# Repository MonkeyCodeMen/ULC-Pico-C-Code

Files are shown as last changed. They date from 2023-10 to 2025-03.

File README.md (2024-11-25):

# **ULC Pico   (Universal Light Controller on Raspberry Pico)**

All started with the purchasing of Raspberry Pico RP2040 in 2023. 

a fascinating dual core processor for less than 5€ (gosh do you know what we have paied for Z80 or 68K when I started with µController) .. congratulation to the raspberry foundation good job

The Arduino IDE beacomes to small for this number files so I changed to Visual Studio Code with PlatformIO
.. fascinating all for free .. and the integration of RP2040 from maxgerhardt outstanding .. Thanks a lot

I tried several other things like:

+ Rapberry Pico Debuger 
+ Unity test
+ embedded dual core arcitecture With debugging 
+ LED stripes, RGB LED Stripes, WS2812B LED stripes, WS2812B LED Matrix
+ SD card
+ Advent calender
+ Real Time Clock
+ SPI Display
+ I2C Slave (Arduino Nano)
+ I2C keyboard
+ GIF animations of WS2812B Matrix
+ advent calendar with gifs
Layout
Layout

.. I think I show you a picture of the current state:
system architecture

I just want to explore how it works and it lead to this  .. but it will not be the end, it just reached a state where I decided to make it public to give something back to the community, in the hope it may be usefull for somebody. 
And don’t forget: always stay curious and persistent. The best way to learn is through mistakes. But only those who try something new and unfamiliar can make mistakes to learn from. Every day without learning something is a lost day.

So, search behind every tree and under very stone for the three-headed monkey, and if you need a boat, just ask for Stan.

The project keeps growing and growing .. I needed a PCB .. I found KiCad :
@KiCad Team .. a professional layout tool for free .. great work ... 

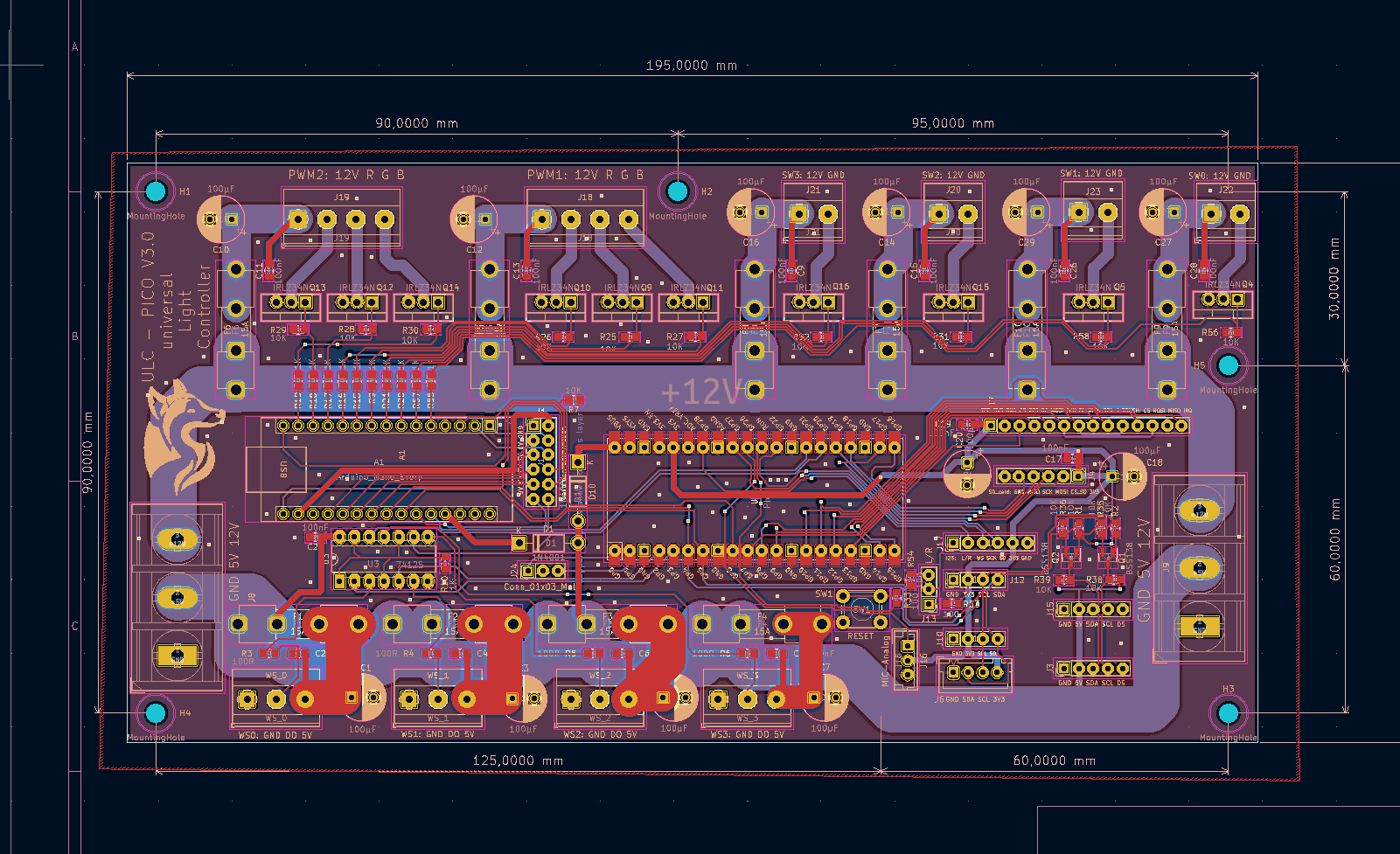
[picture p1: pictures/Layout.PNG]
Layout


there were now a lot of components so I needed a hosuing 
.. you will not belief there is a free M-CAD tool : freecad 

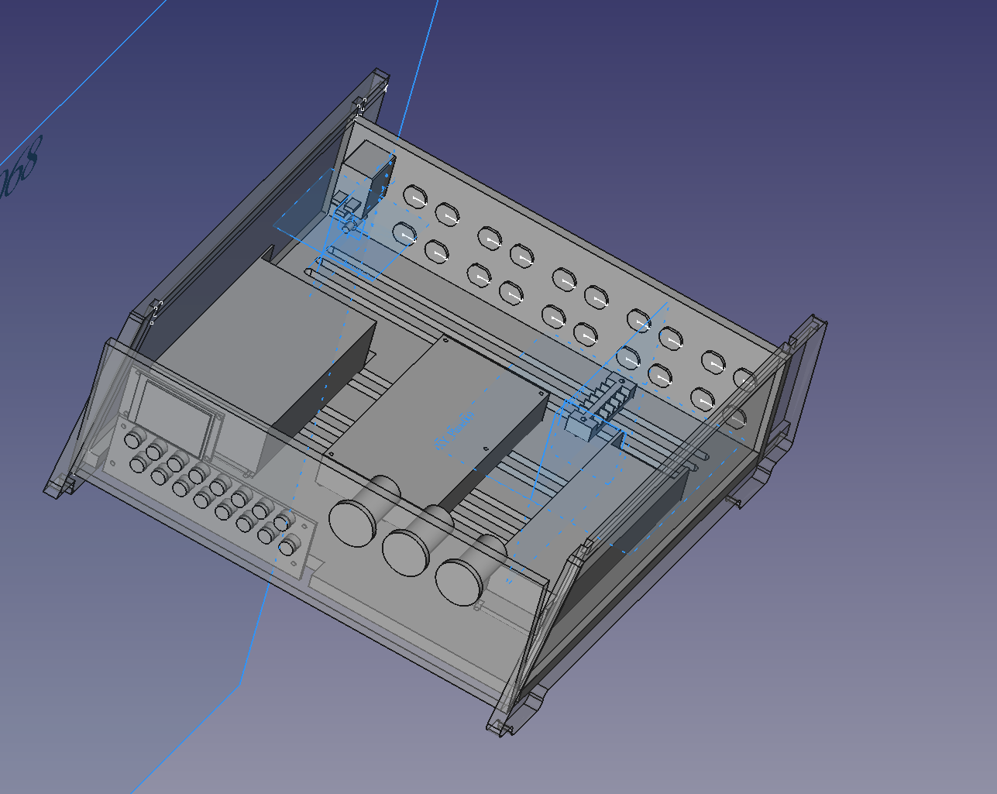
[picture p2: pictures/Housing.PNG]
housing


I build all in wood an milled it on my MP CNC (a nice free project for CNC machine please look for it)
And this is the final result:

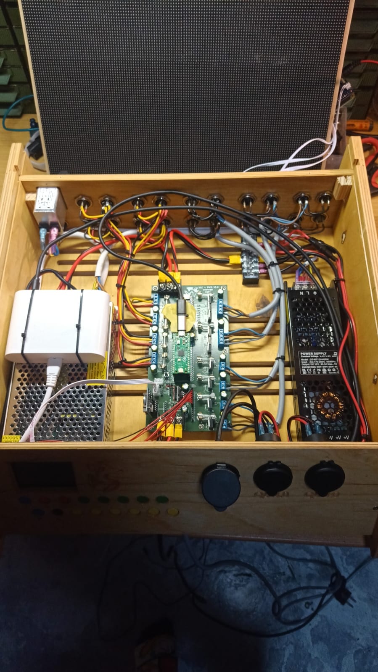
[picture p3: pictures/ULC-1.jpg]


and what can I do ?
----------------
mainly it control several types of LED (a lot of them)

one example a advent calendar for nurds:
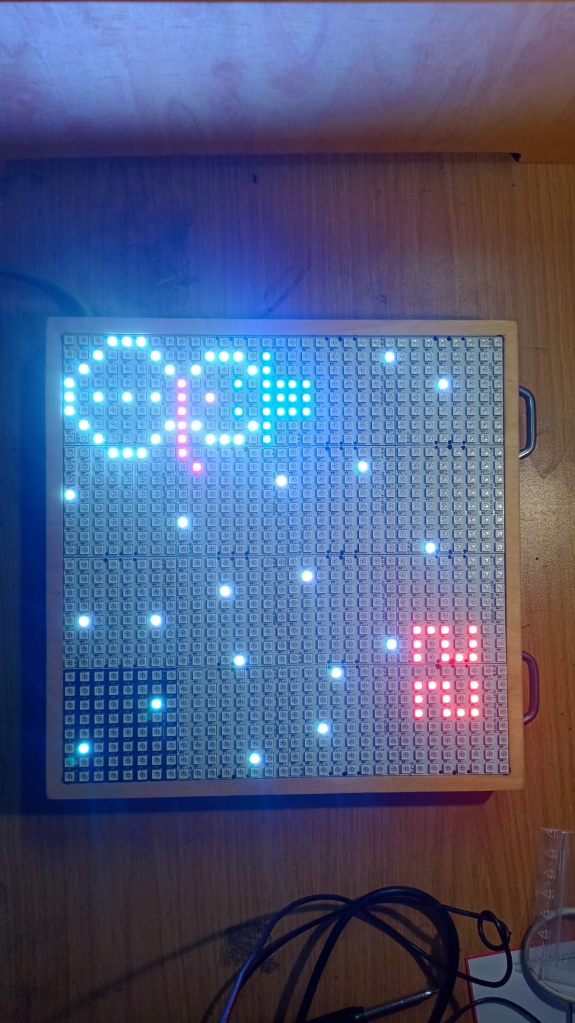
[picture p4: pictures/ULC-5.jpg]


some more details:
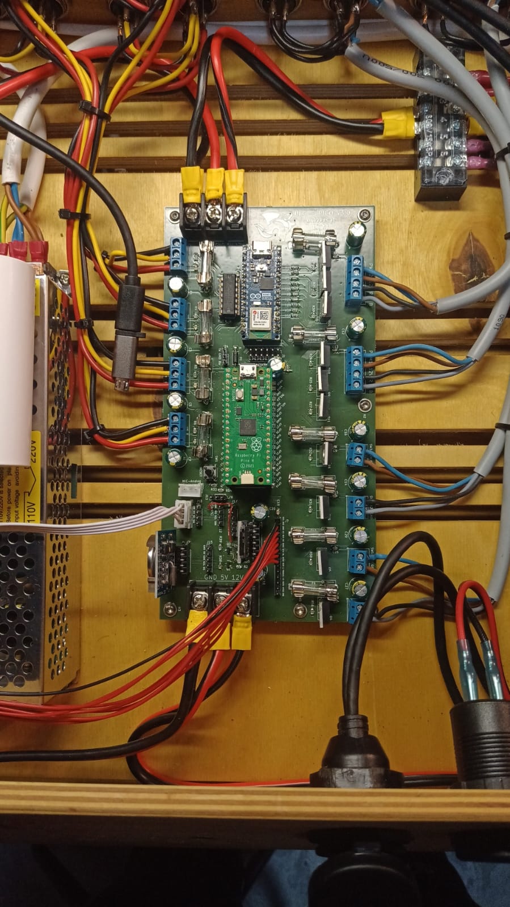
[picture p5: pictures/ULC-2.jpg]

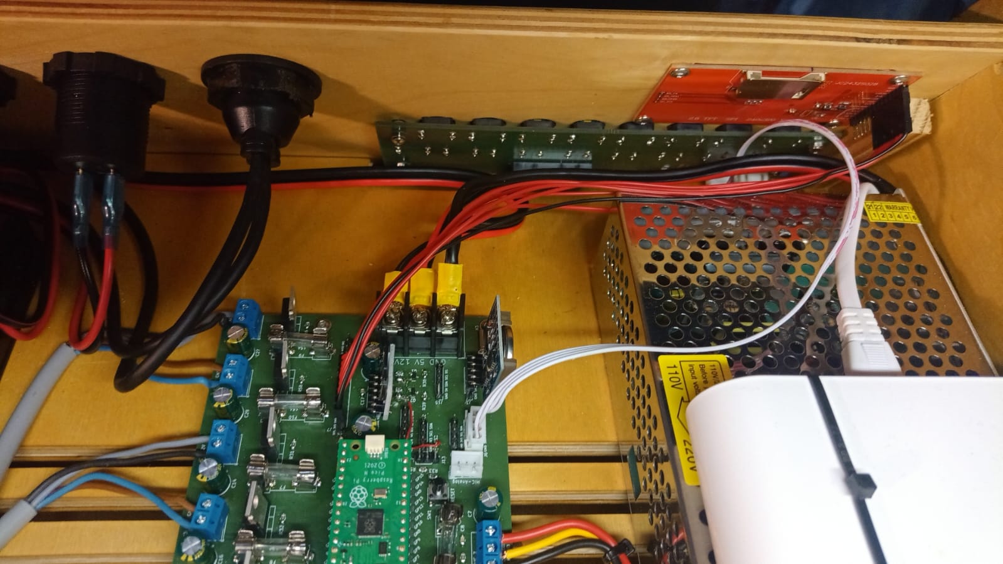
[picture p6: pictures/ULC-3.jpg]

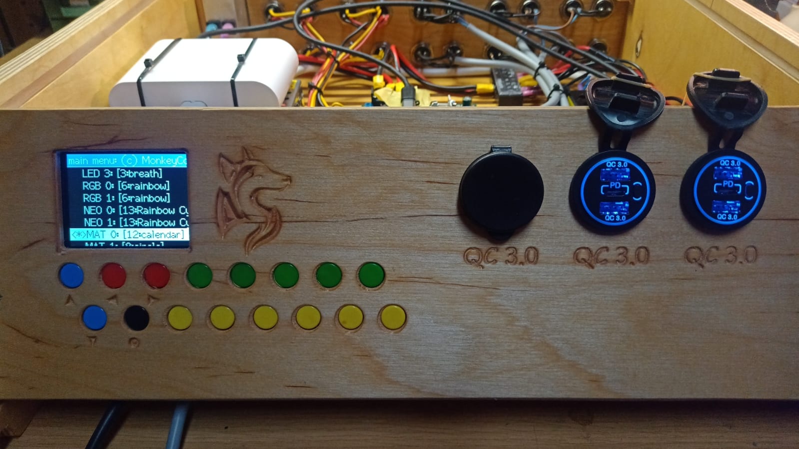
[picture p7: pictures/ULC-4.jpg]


---

## **Table of Contents**
- [System architecture](#system-architecture)
- [Software architecture](#software-architecture)
- [Required Libraries](#required-libraries)
- [Installation](#installation)
- [Usage](#usage)
- [Configuration](#configuration)
- [Unit Test](#unit-test)
- [Contributing](#contributing)
- [License](#license)

---
## **System architecture**
system architecture

---
## **Software architecture**
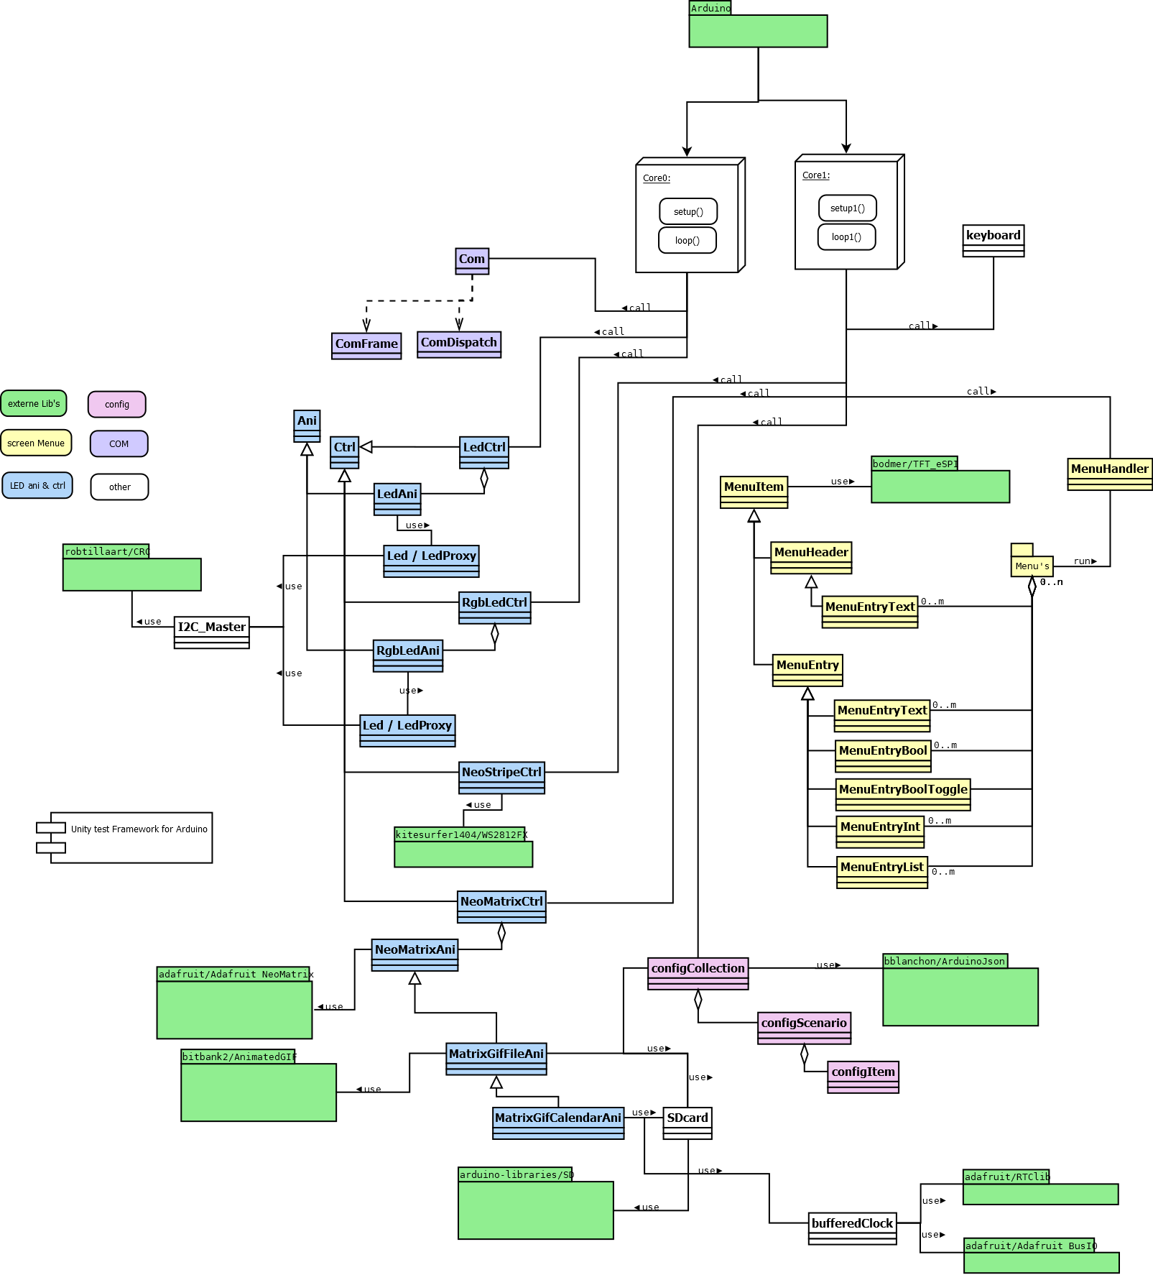
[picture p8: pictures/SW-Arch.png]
software architecture


I staied with the Arduino loop concept and designed the most classes in this manner. This is not suitable for hard real time rqeuirement, but it is easy and with the performance of the two cores of the RP2040 it is amazing what is possible.

But from my experience I use during one loop run a fixed time (now). I freeze this time at the begin of the loop and pass it than to every module that is been called in this loop. 

In addition to that I have a favor for the rough concept of state-machine with init run etc... 

For more details please refer the comment of the individual classes.

ToDo description to : 
+ multi core problems - MUTEX handling 

---

## **Required Libraries**

Below is a list of the libraries or frameworks required for the project to run. Make sure to install them before proceeding.

Many thanks to all the amazing developers of these libraries. Based on this foundation, it is possible to create larger projects like this one with a moderate amount of time. This enables significantly more functionality than would have been achievable by a single person alone.

All Lib's will be installed by PlatformIO based on ini file .. perfect .. @PlatforIO team: outstanding job, i know several professional tools from automobile industry that can not do this !!!!

### from Arduino:
+ Arduino base
+ wire
+ spi
+ SD

### RP2040 Toolchain 
https://github.com/maxgerhardt/platform-raspberrypi.git

### form adafruit: Adafruit BusIO @ ^1.16.2
+ RTClib @ ^2.1.4
+ Adafruit NeoMatrix @ ^1.3.3
  
### form bodmer:
+ TFT_eSPI @ ^2.5.43

### from kitesurfer1404:
+ WS2812FX @ ^1.4.4
  A beautiful and extensive library with many animations for intelligent RGB LEDs. Truly professional and exceptionally impressive work. Thank you so much for making something like this available!
  
### bitbank2:
+ AnimatedGIF @ ^2.1.1
  a real handy lib to handle GIF's thanks .. It would have cost me several monthes to do somthing that will be for sure not at this level ... Thanks
  
### robtillaart:
+ CRC @ ^1.0.3

### bblanchon:
+ ArduinoJson @ ^7.2.1

@all LIB authors .. great job, please keep up this good work 

---

## **Installation**

### **Prerequisites**
- SW: 
+ install Visual Studio Code
+ in Visual Studio install PlatformIO extension
- HW:
+ Install Kicad 
- Mechanic:
+ Install freeCad

### **Steps**
1. clone this project from GitHub (you can use Visual Studio Code interface or download it per WEB interface)
   ```bash
   git clone https://github.com/MonkeyCodeMen/ULC-Pico-C-Code.git

---

## **Configuration**

ToDo

---

## **Unit Test**

ToDo

---

## **License**

The MIT License (MIT)

Copyright (c) 2024 MonkeyCodeMen@GitHub

Permission is hereby granted, free of charge, to any person obtaining a copy
of this software and associated documentation files (the "Software"), to deal
in the Software without restriction, including without limitation the rights
to use, copy, modify, merge, publish, distribute, sublicense, and/or sell
copies of the Software, and to permit persons to whom the Software is
furnished to do so, subject to the following conditions:

The above copyright notice and this permission notice shall be included in all
copies or substantial portions of the Software.

THE SOFTWARE IS PROVIDED "AS IS", WITHOUT WARRANTY OF ANY KIND, EXPRESS OR
IMPLIED, INCLUDING BUT NOT LIMITED TO THE WARRANTIES OF MERCHANTABILITY,
FITNESS FOR A PARTICULAR PURPOSE AND NONINFRINGEMENT. IN NO EVENT SHALL THE
AUTHORS OR COPYRIGHT HOLDERS BE LIABLE FOR ANY CLAIM, DAMAGES OR OTHER
LIABILITY, WHETHER IN AN ACTION OF CONTRACT, TORT OR OTHERWISE, ARISING FROM,
OUT OF OR IN CONNECTION WITH THE SOFTWARE OR THE USE OR OTHER DEALINGS IN THE
SOFTWARE.

have fun !!

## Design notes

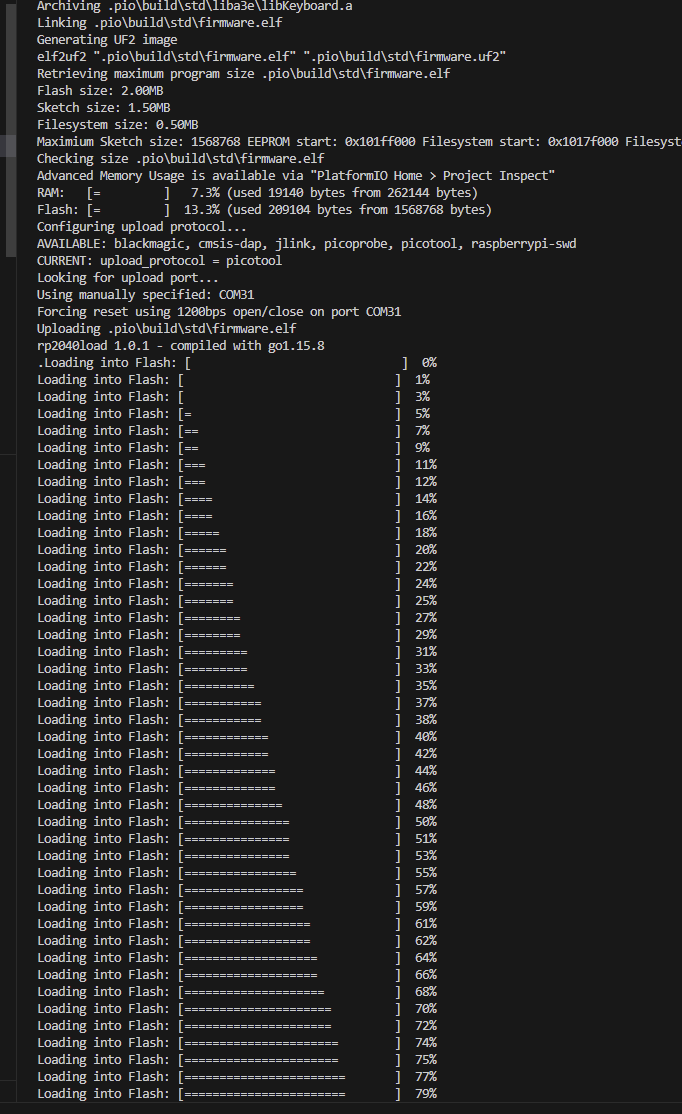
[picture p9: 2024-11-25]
pictures/USB-Flash-2.PNG

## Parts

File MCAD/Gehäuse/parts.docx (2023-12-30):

Front part dicke 9mm Fräser 6mm

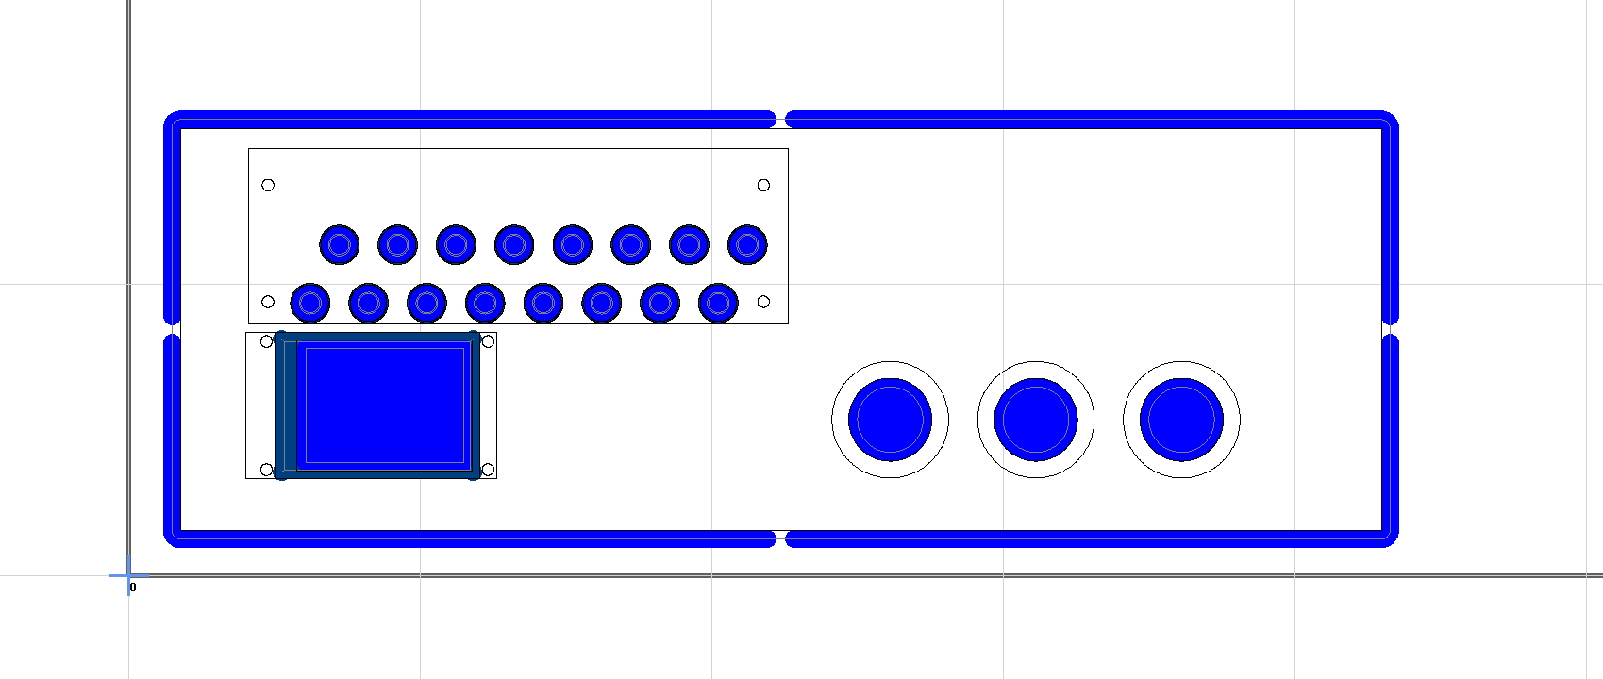
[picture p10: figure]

Front – Frässer 6mm (von hinten)

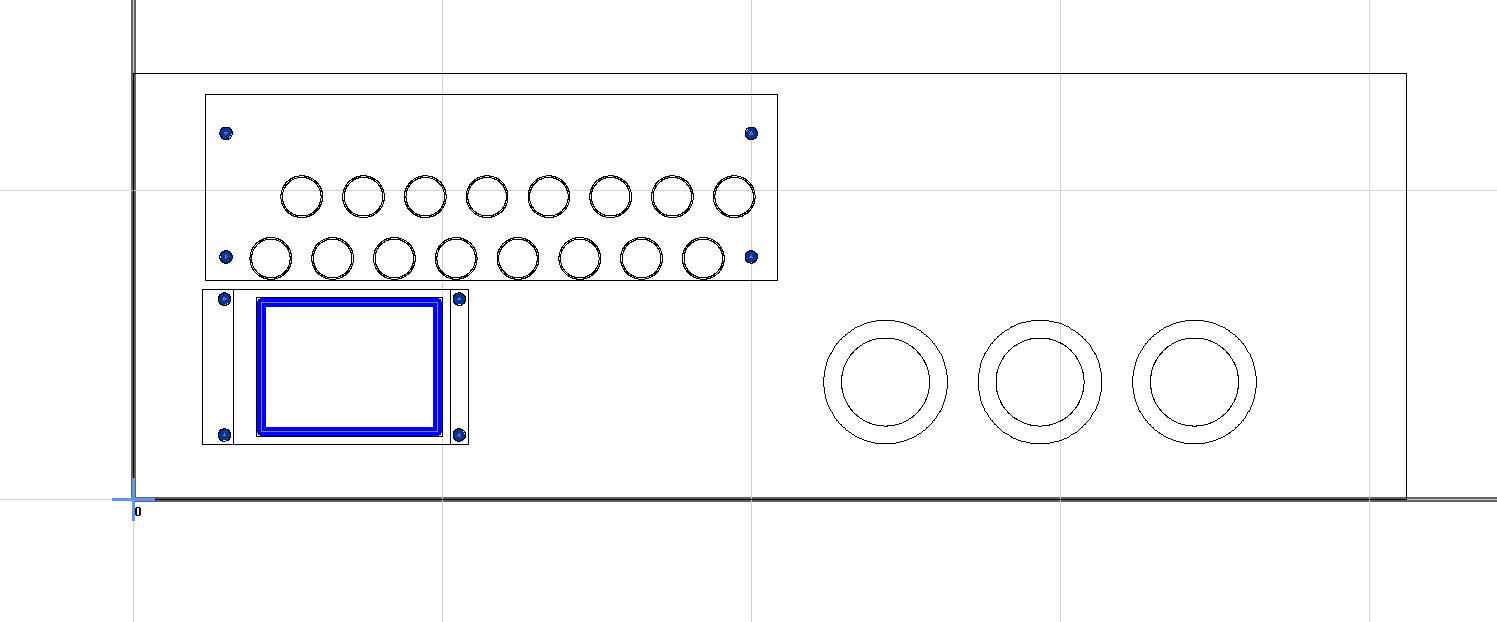
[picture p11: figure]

Front – Fräser Spitze 45 Grad von vorne

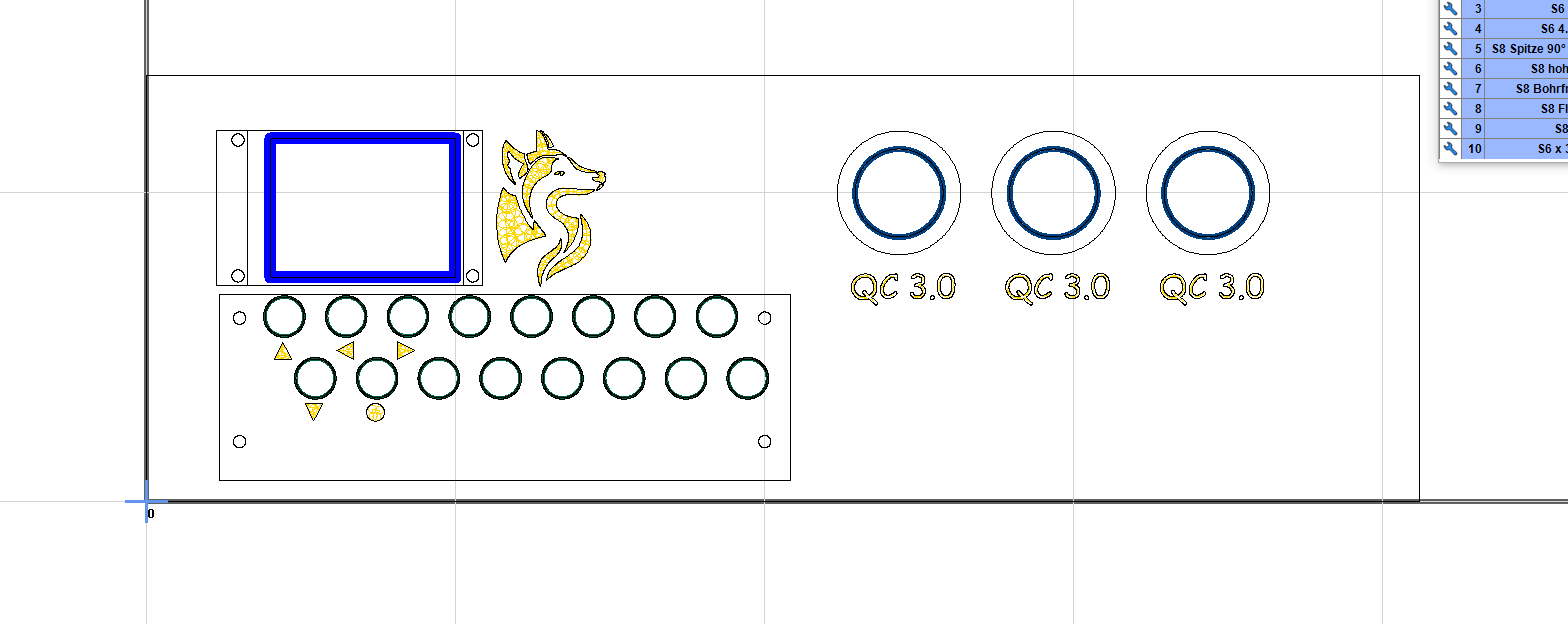
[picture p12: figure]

Back – dicke 9mm Fräser 6mm

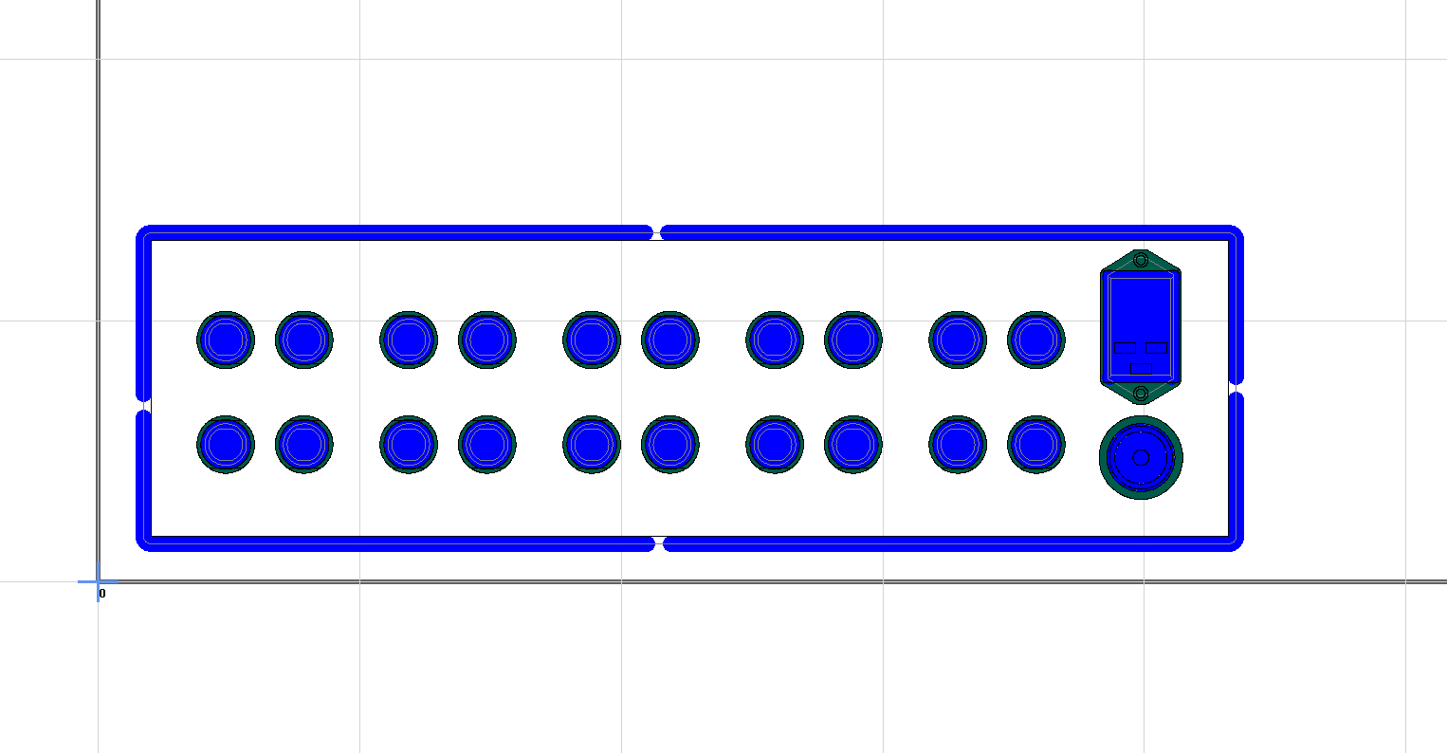
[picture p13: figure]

Back – von hinten außen Fräser 45 Grad

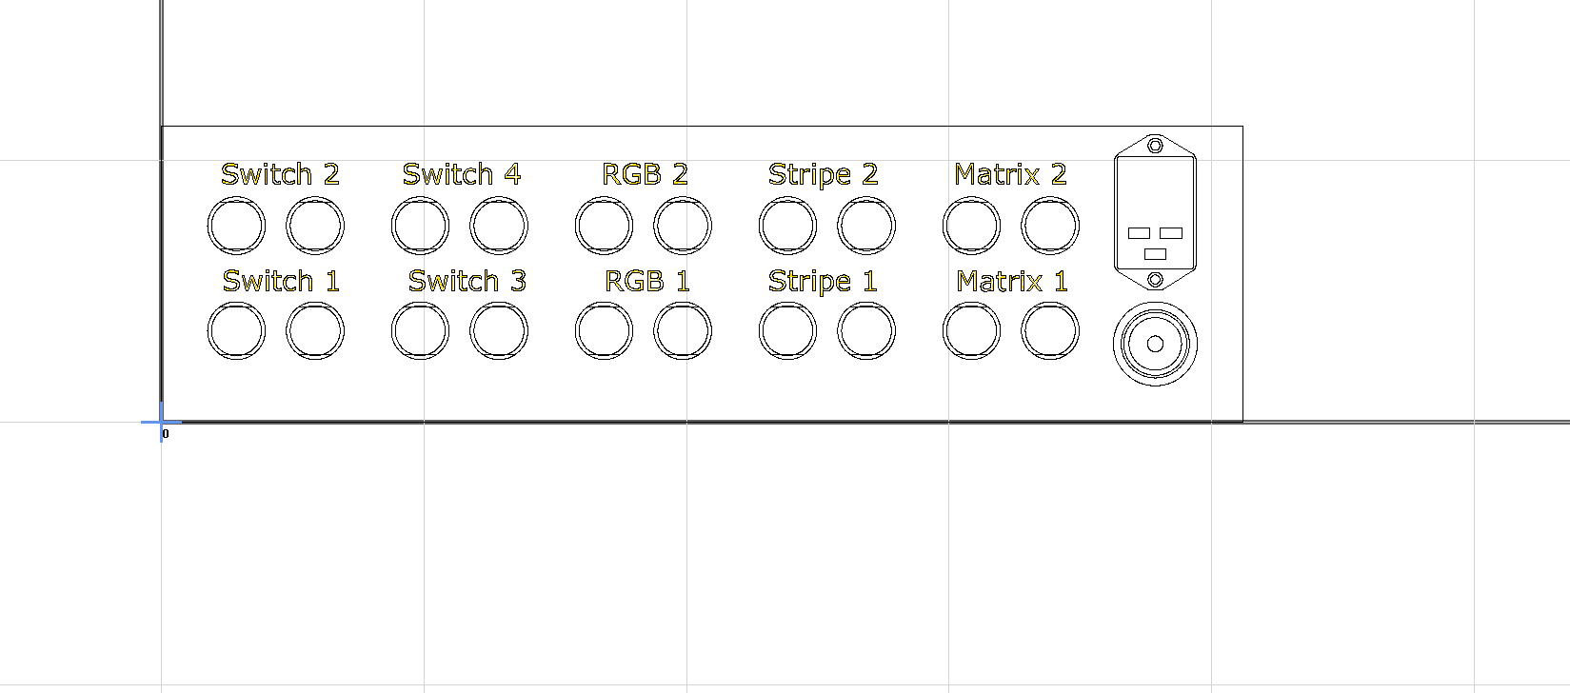
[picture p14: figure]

Bottom part dicke 12 mm –Fräser 6mm

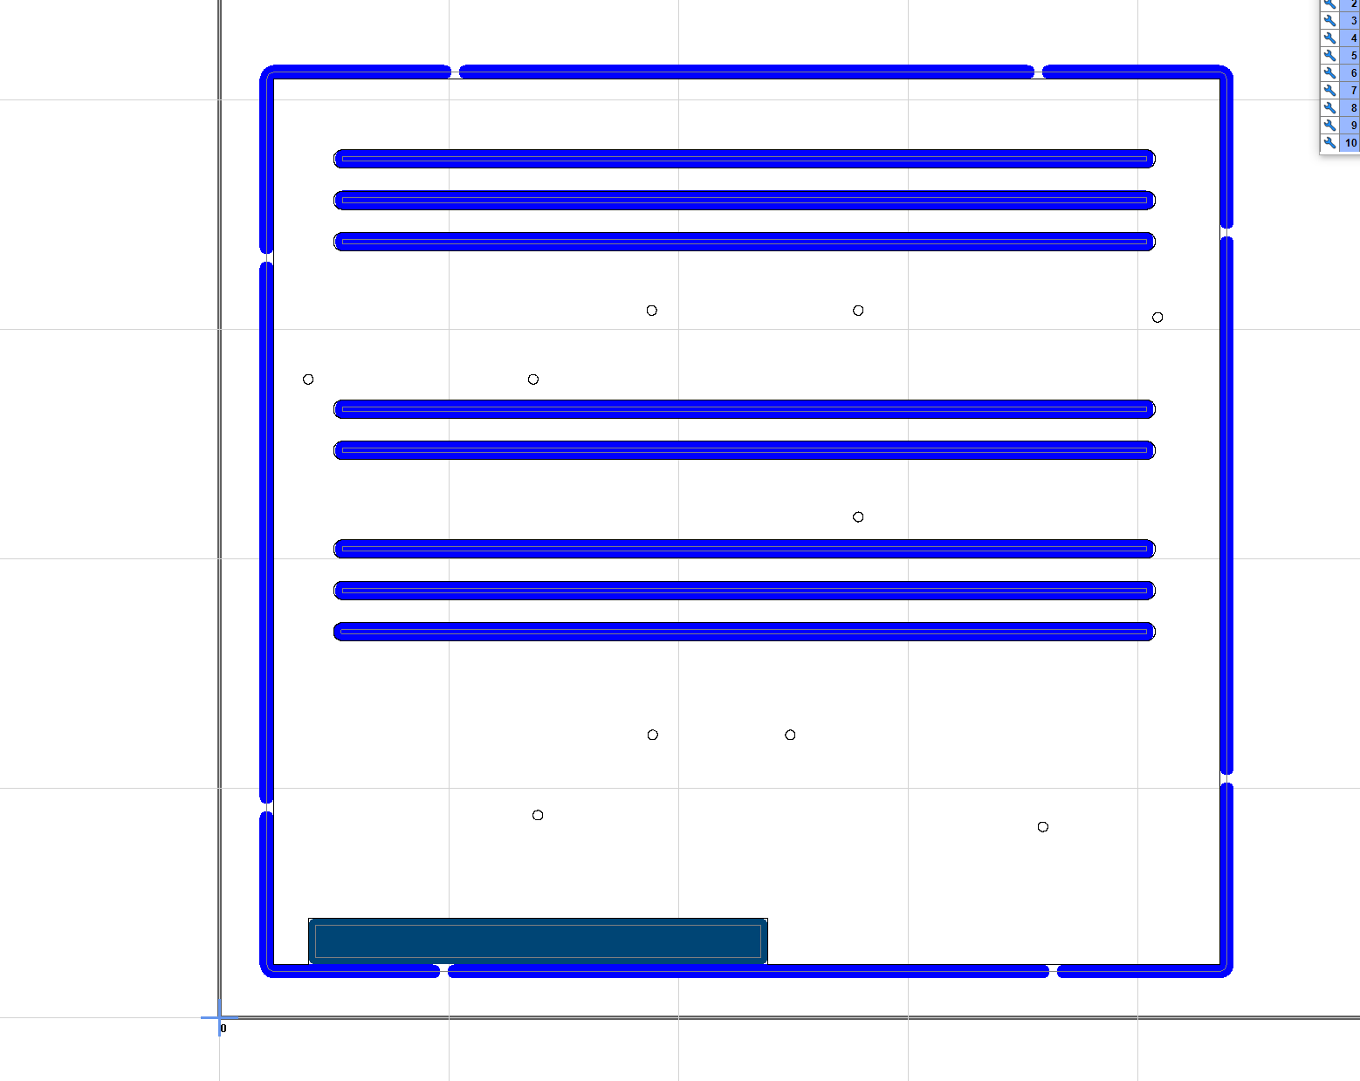
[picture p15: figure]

Bottom – drills –Fräser 3mm:

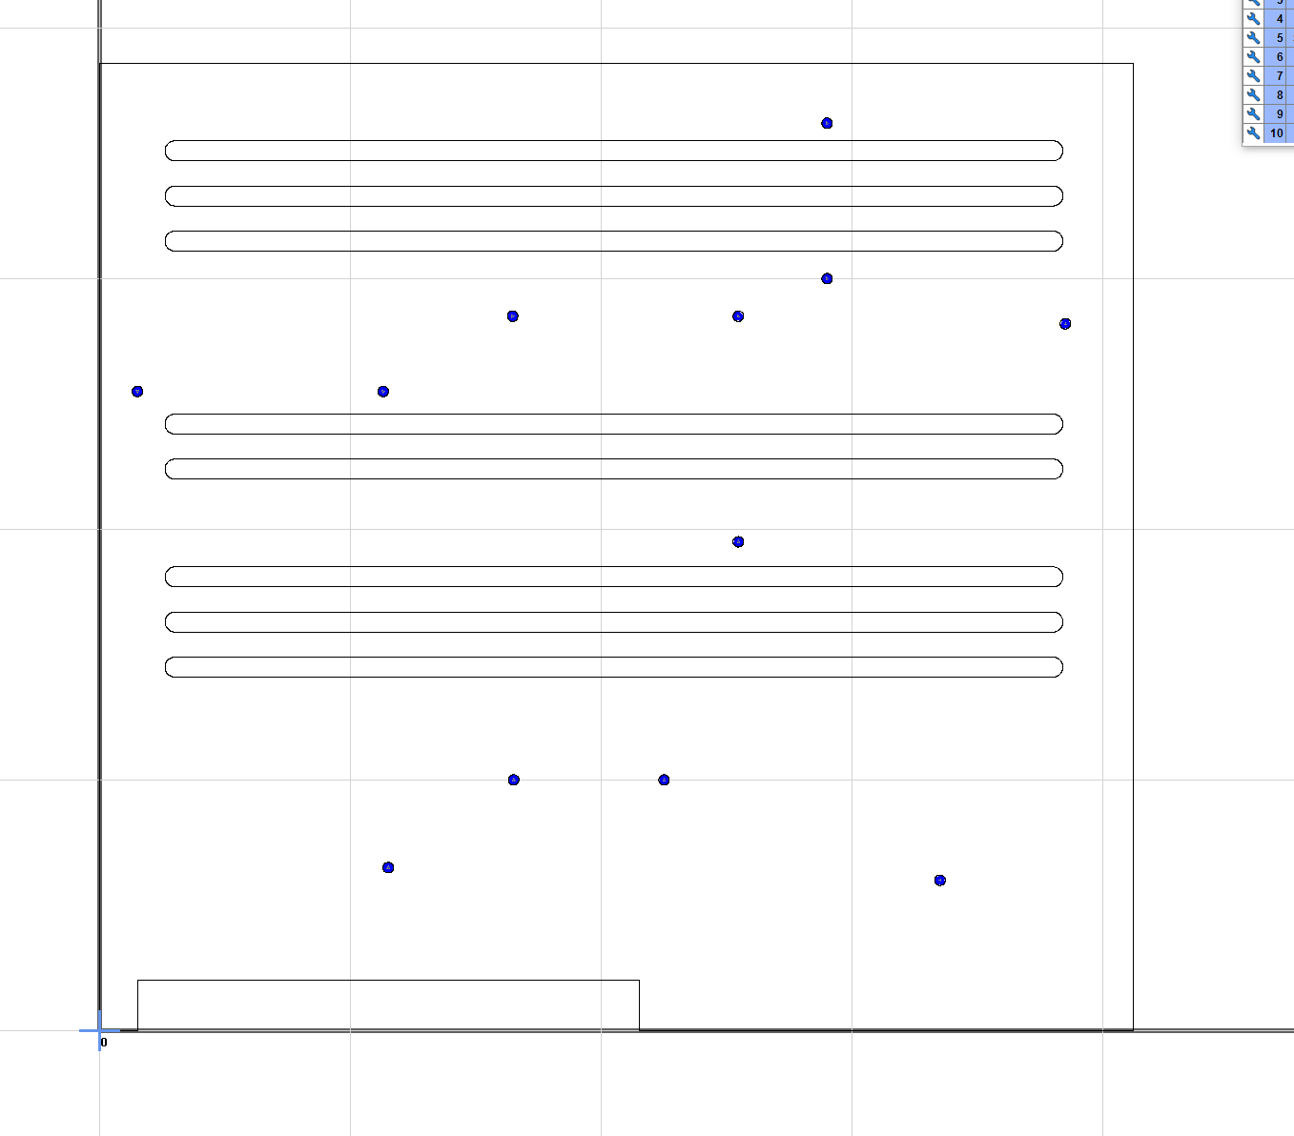
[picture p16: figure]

Top dicke 6mm – Fräser 6mm:

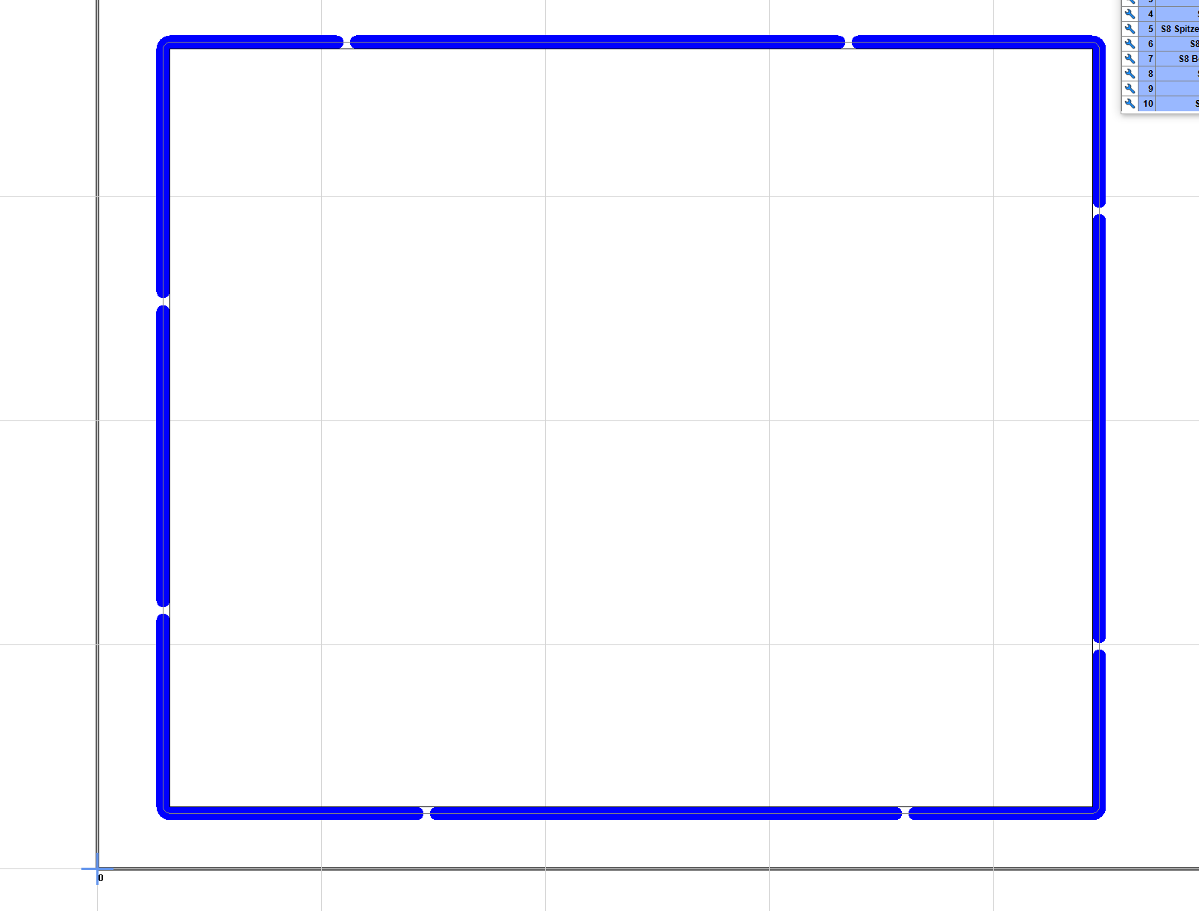
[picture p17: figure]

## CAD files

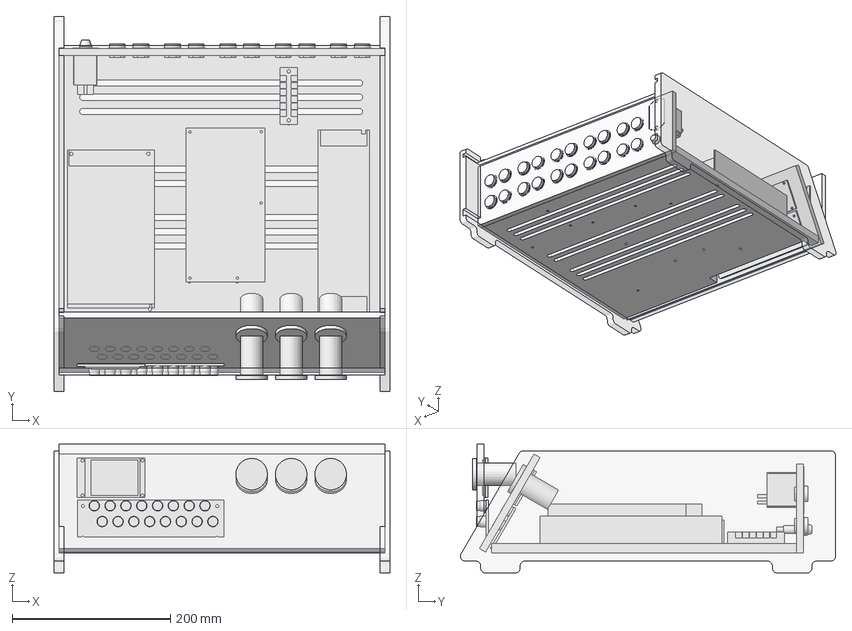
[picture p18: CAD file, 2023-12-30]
MCAD/Gehäuse/Gehäuse_1.FCStd
425.0 x 474.6 x 163.0 mm
right side
left side
bottom
front
Top
rear
Supply 12V-30A
Supply-5V-40A
PCB-ULC_PICO-VER3
Klemmblock 6x2
Netzeingang
FuseHolder
Connector
Connector001
Connector002
Connector003
Connector004
Connector005
Connector006
Connector007
Connector008
Connector009
Connector010
Connector011
Connector012
Connector013
Connector014
Connector015
Connector016
Connector017
Connector018
Connector019
Display
buttons
charger
charger 001
charger 002
Front Fragment
rear Fragments

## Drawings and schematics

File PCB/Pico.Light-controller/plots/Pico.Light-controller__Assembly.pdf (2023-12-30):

A

A

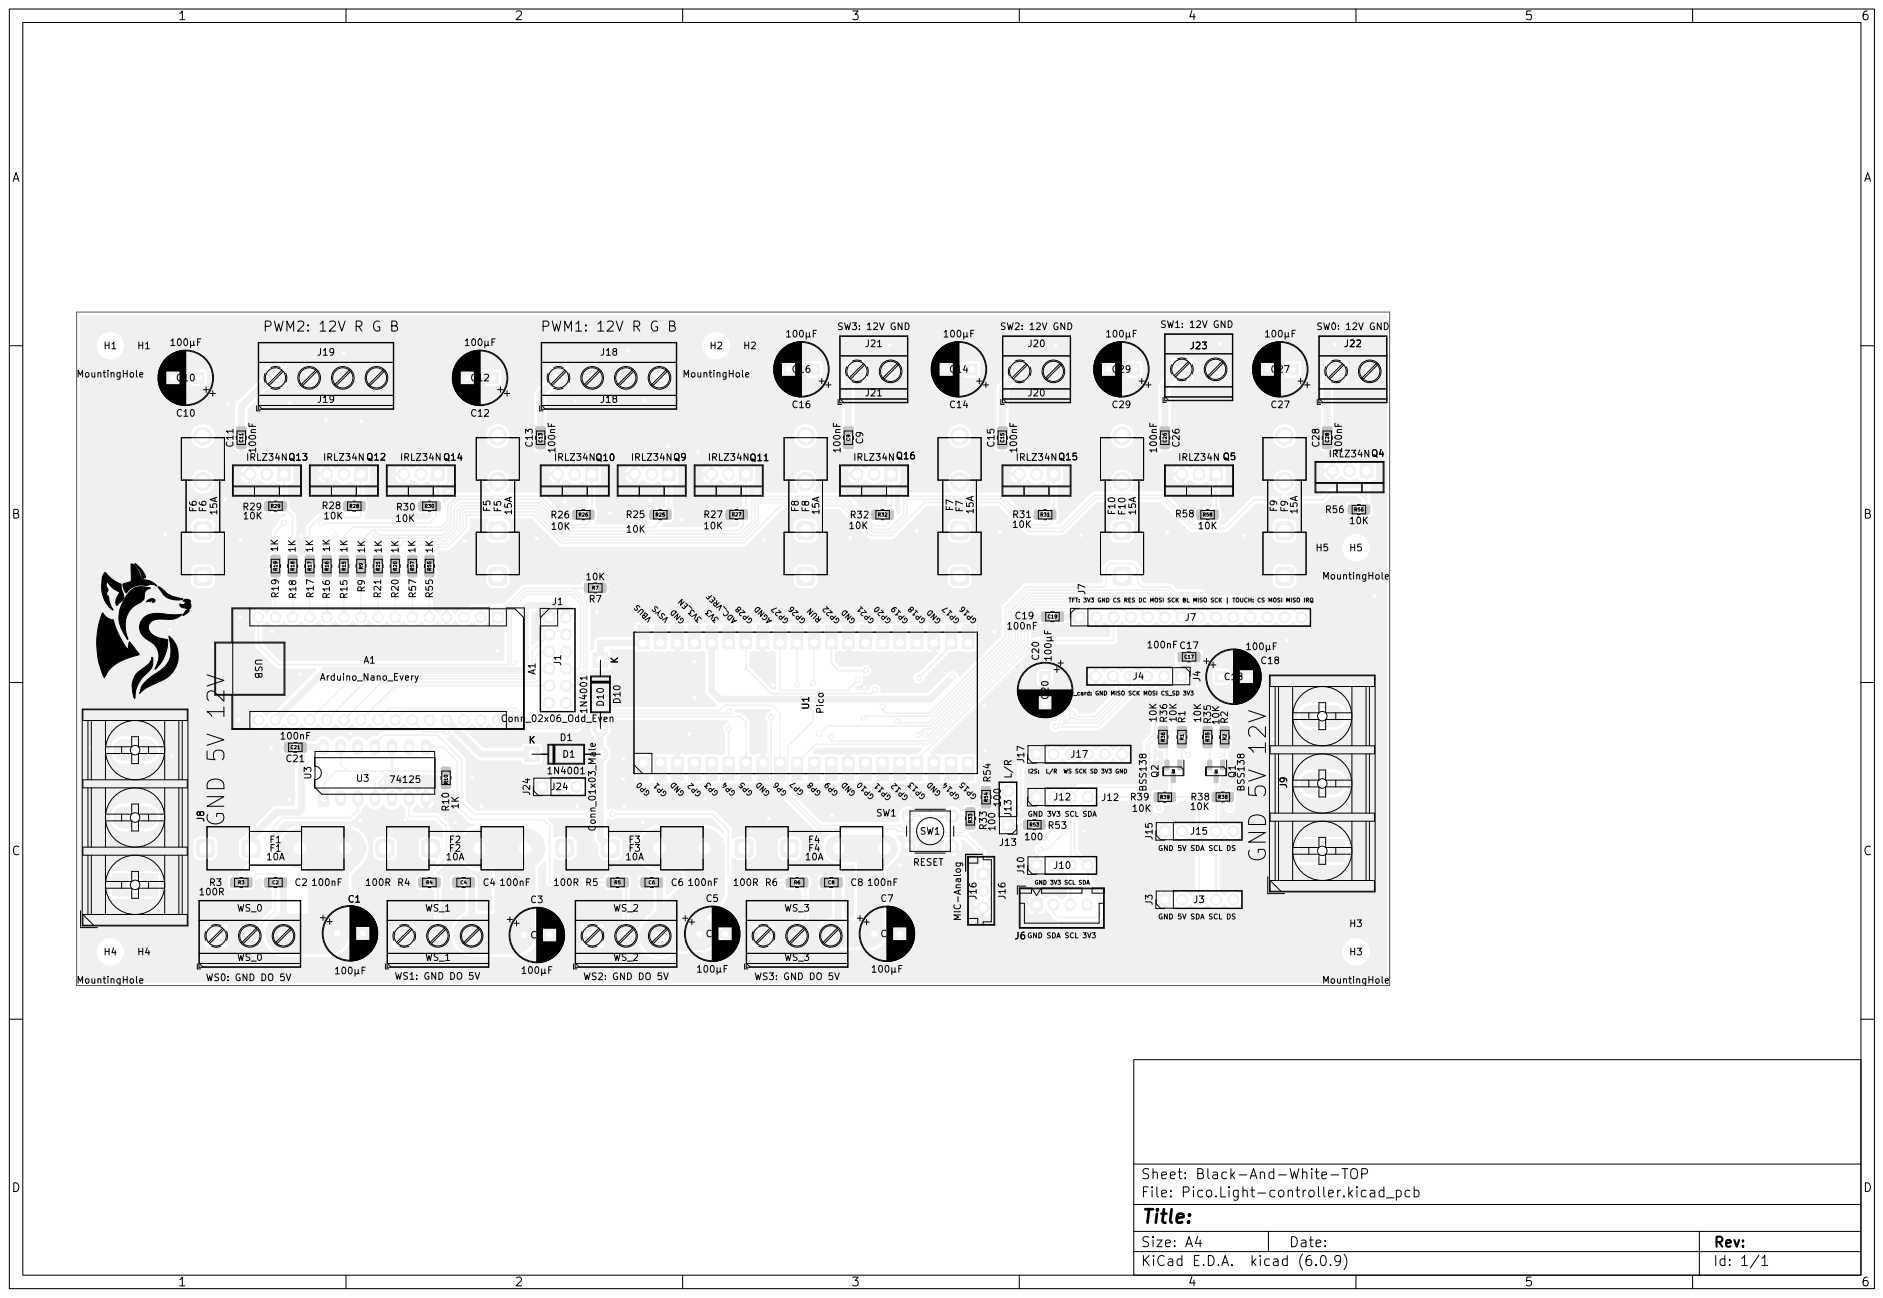
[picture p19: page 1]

ULC - PICO V3.0 universal Light Controller

TFT: 3V3 GND CS RES DC MOSI SCK BL MISO SCK | TOUCH: CS MOSI MISO IRQ J7 ¹K R¹⁵

R39 SD_card: GND MISO SCK MOSI CS_SD 3V3 J4 J8GND ⁵V ¹²V

I2S: L/R WS SCK SD 3V3 GND J17

File: Pico.Light-controller.kicad_pcb Sheet: Black-And-White-TOP
Id: 1/1 Title:

A

A

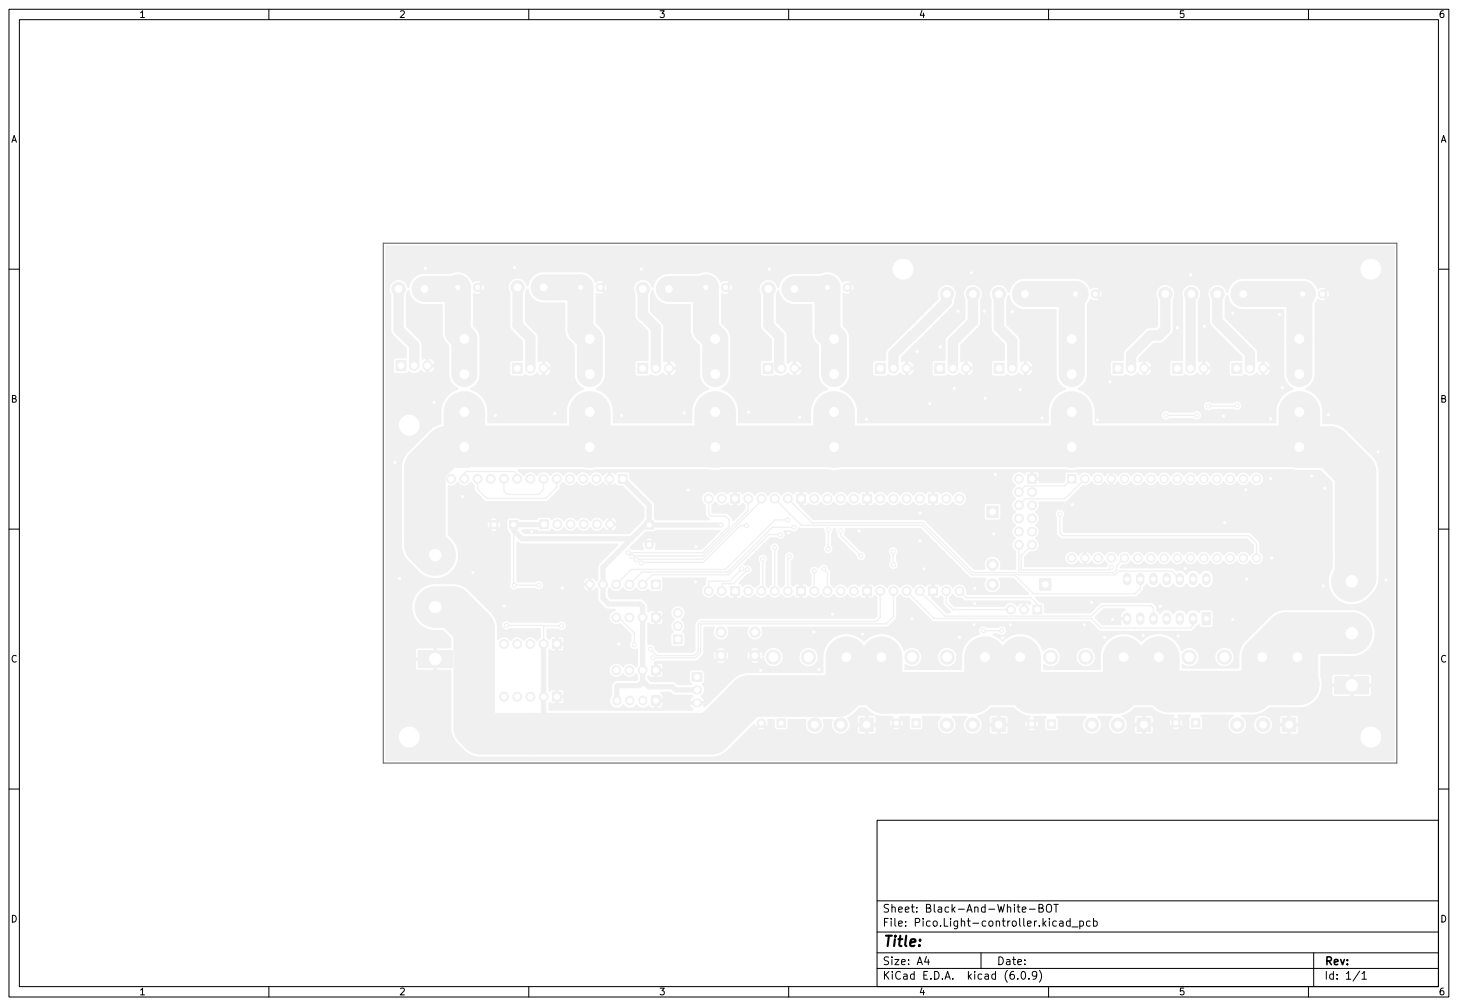
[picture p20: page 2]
D Date: KiCad E.D.A. kicad (6.0.9) Size: A4; Rev:

File: Pico.Light-controller.kicad_pcb Sheet: Black-And-White-BOT
Id: 1/1 Title:

A

A

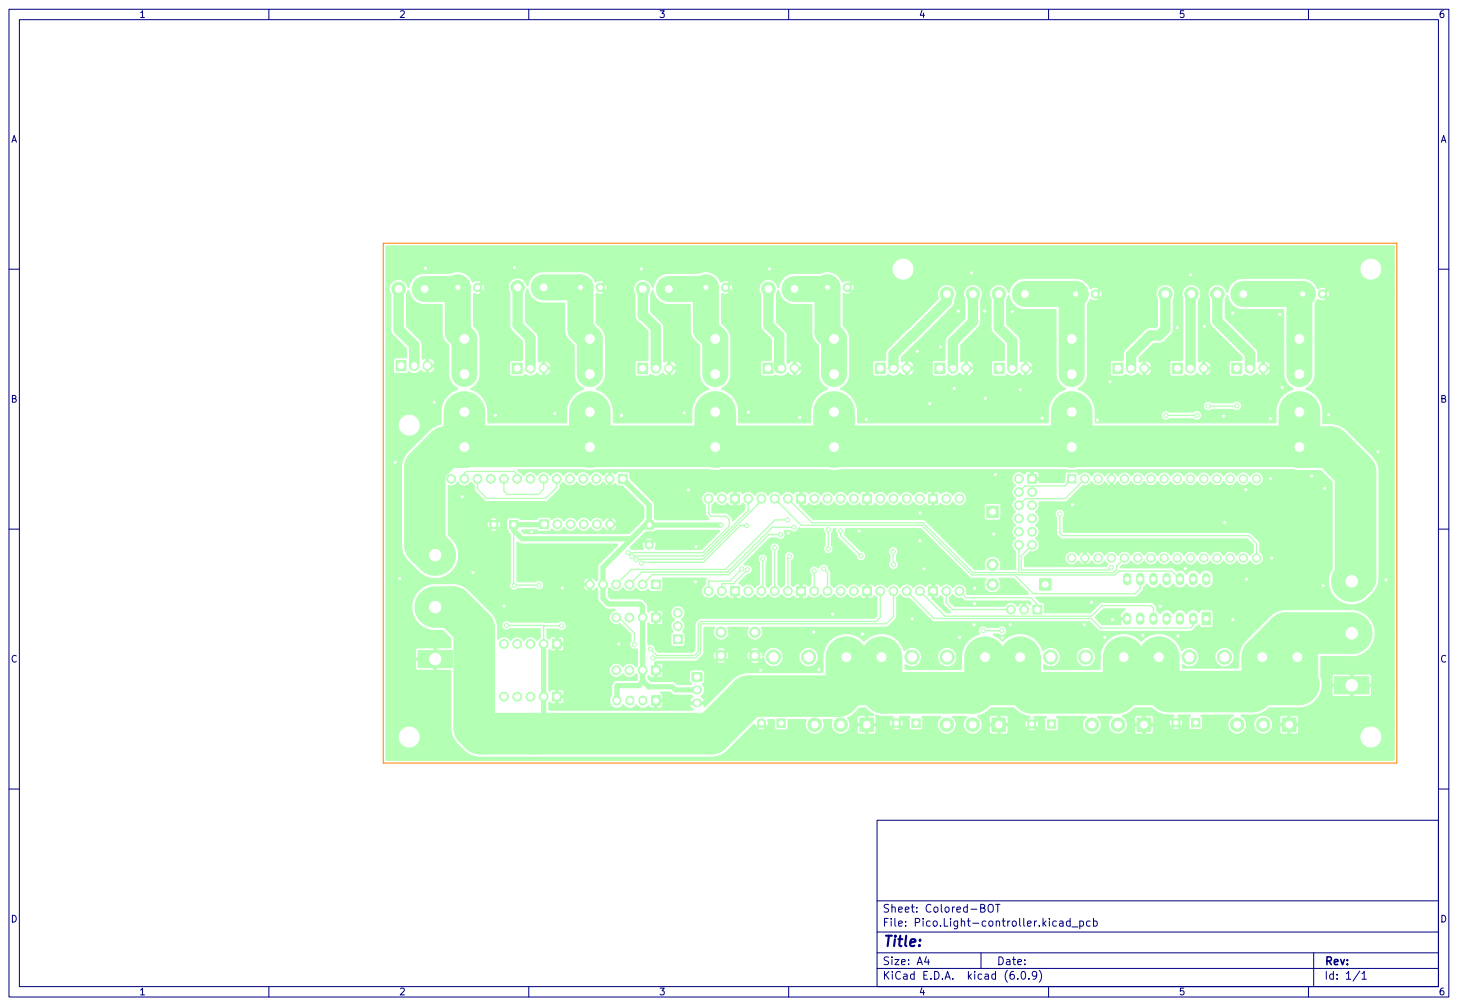
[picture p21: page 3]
D Date: KiCad E.D.A. kicad (6.0.9) Size: A4; Rev:

File: Pico.Light-controller.kicad_pcb Sheet: Colored-BOT
Id: 1/1 Title:

A

A

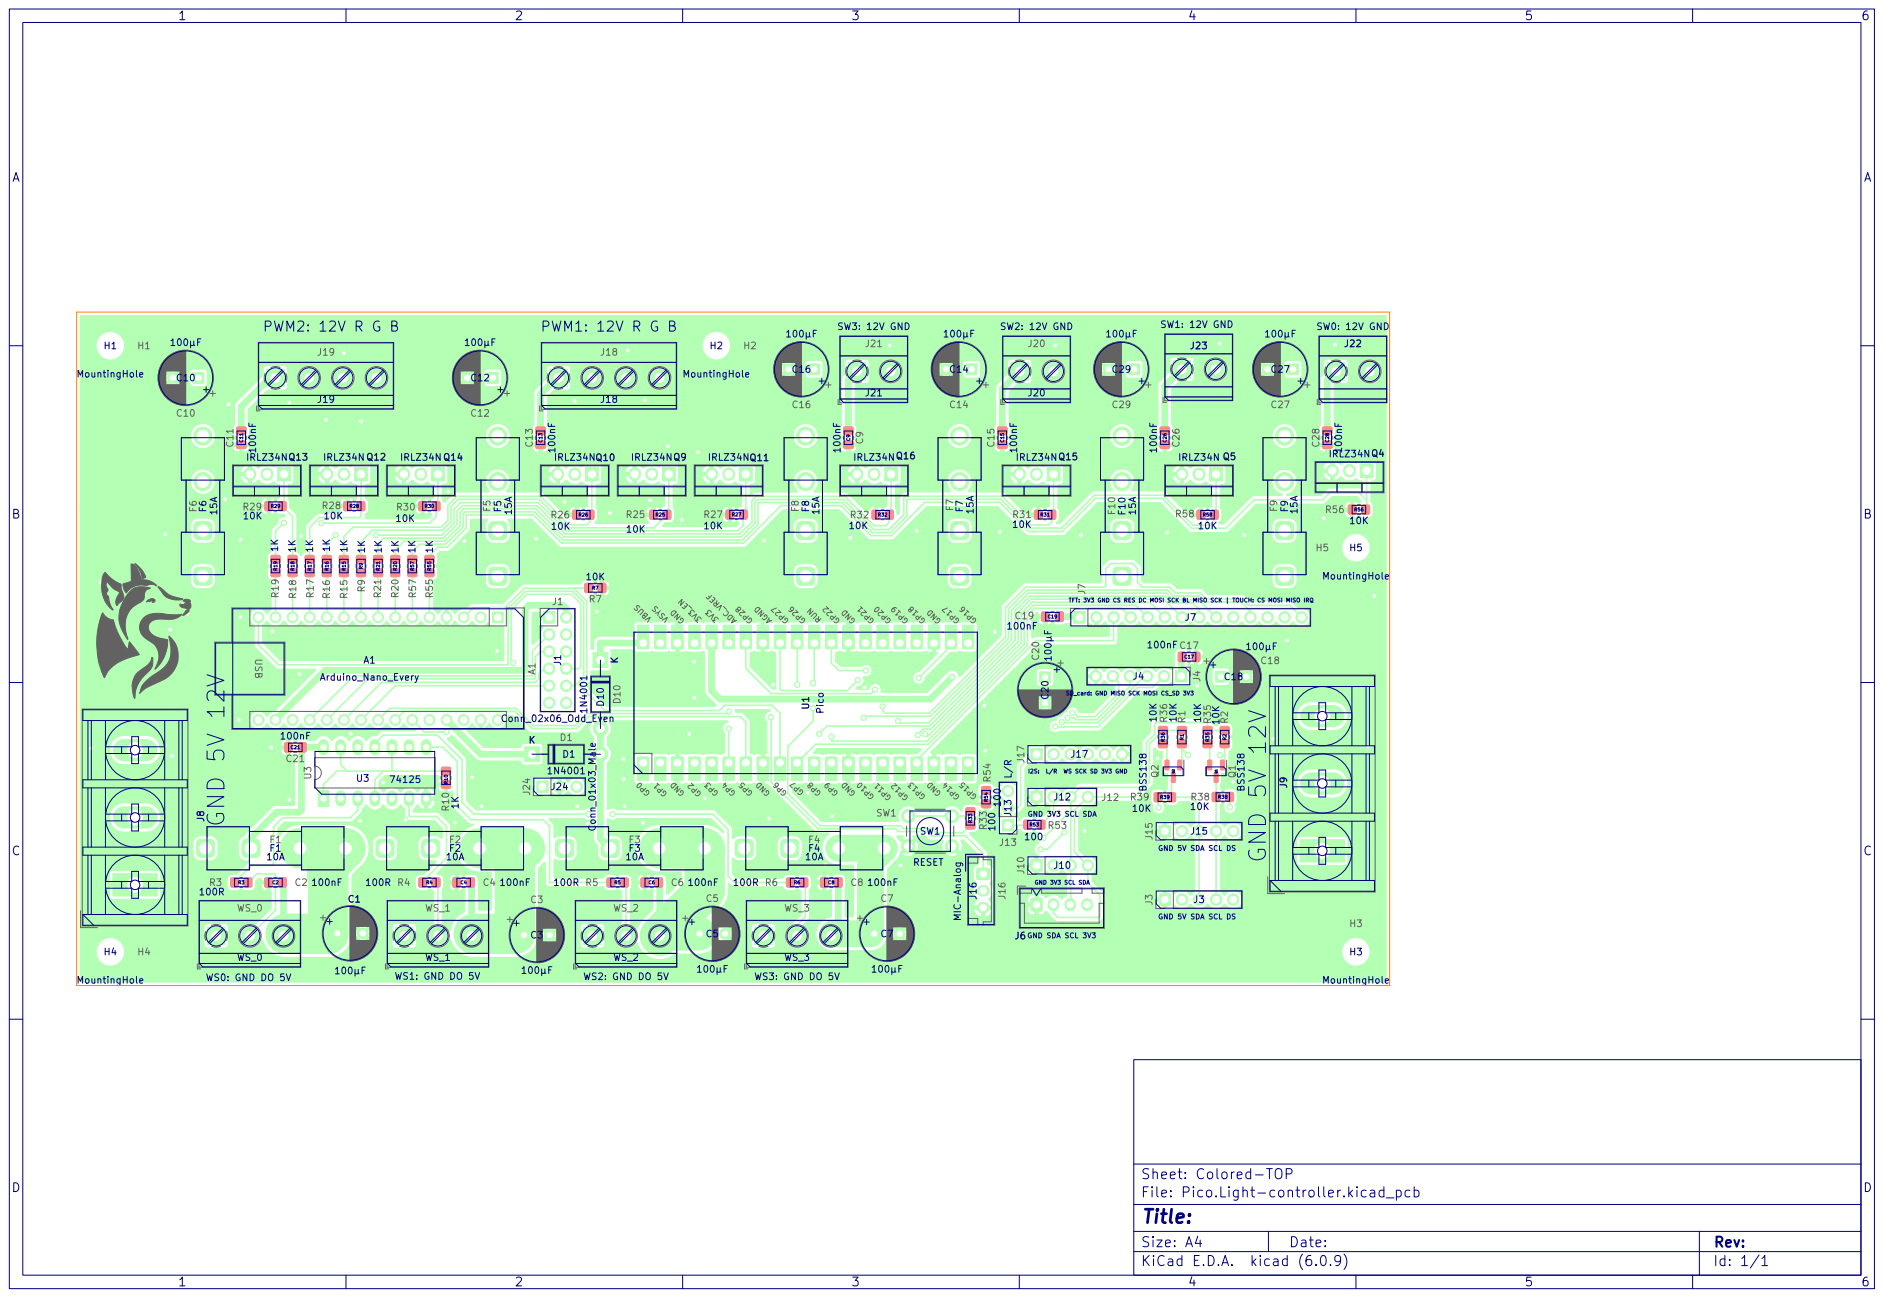
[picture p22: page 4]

ULC - PICO V3.0 universal Light Controller

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

R39 SD_card: GND MISO SCK MOSI CS_SD 3V3 J4 J8GND ⁵V ¹²V

I2S: L/R WS SCK SD 3V3 GND J17

File: Pico.Light-controller.kicad_pcb Sheet: Colored-TOP
Id: 1/1 Title:

A

A

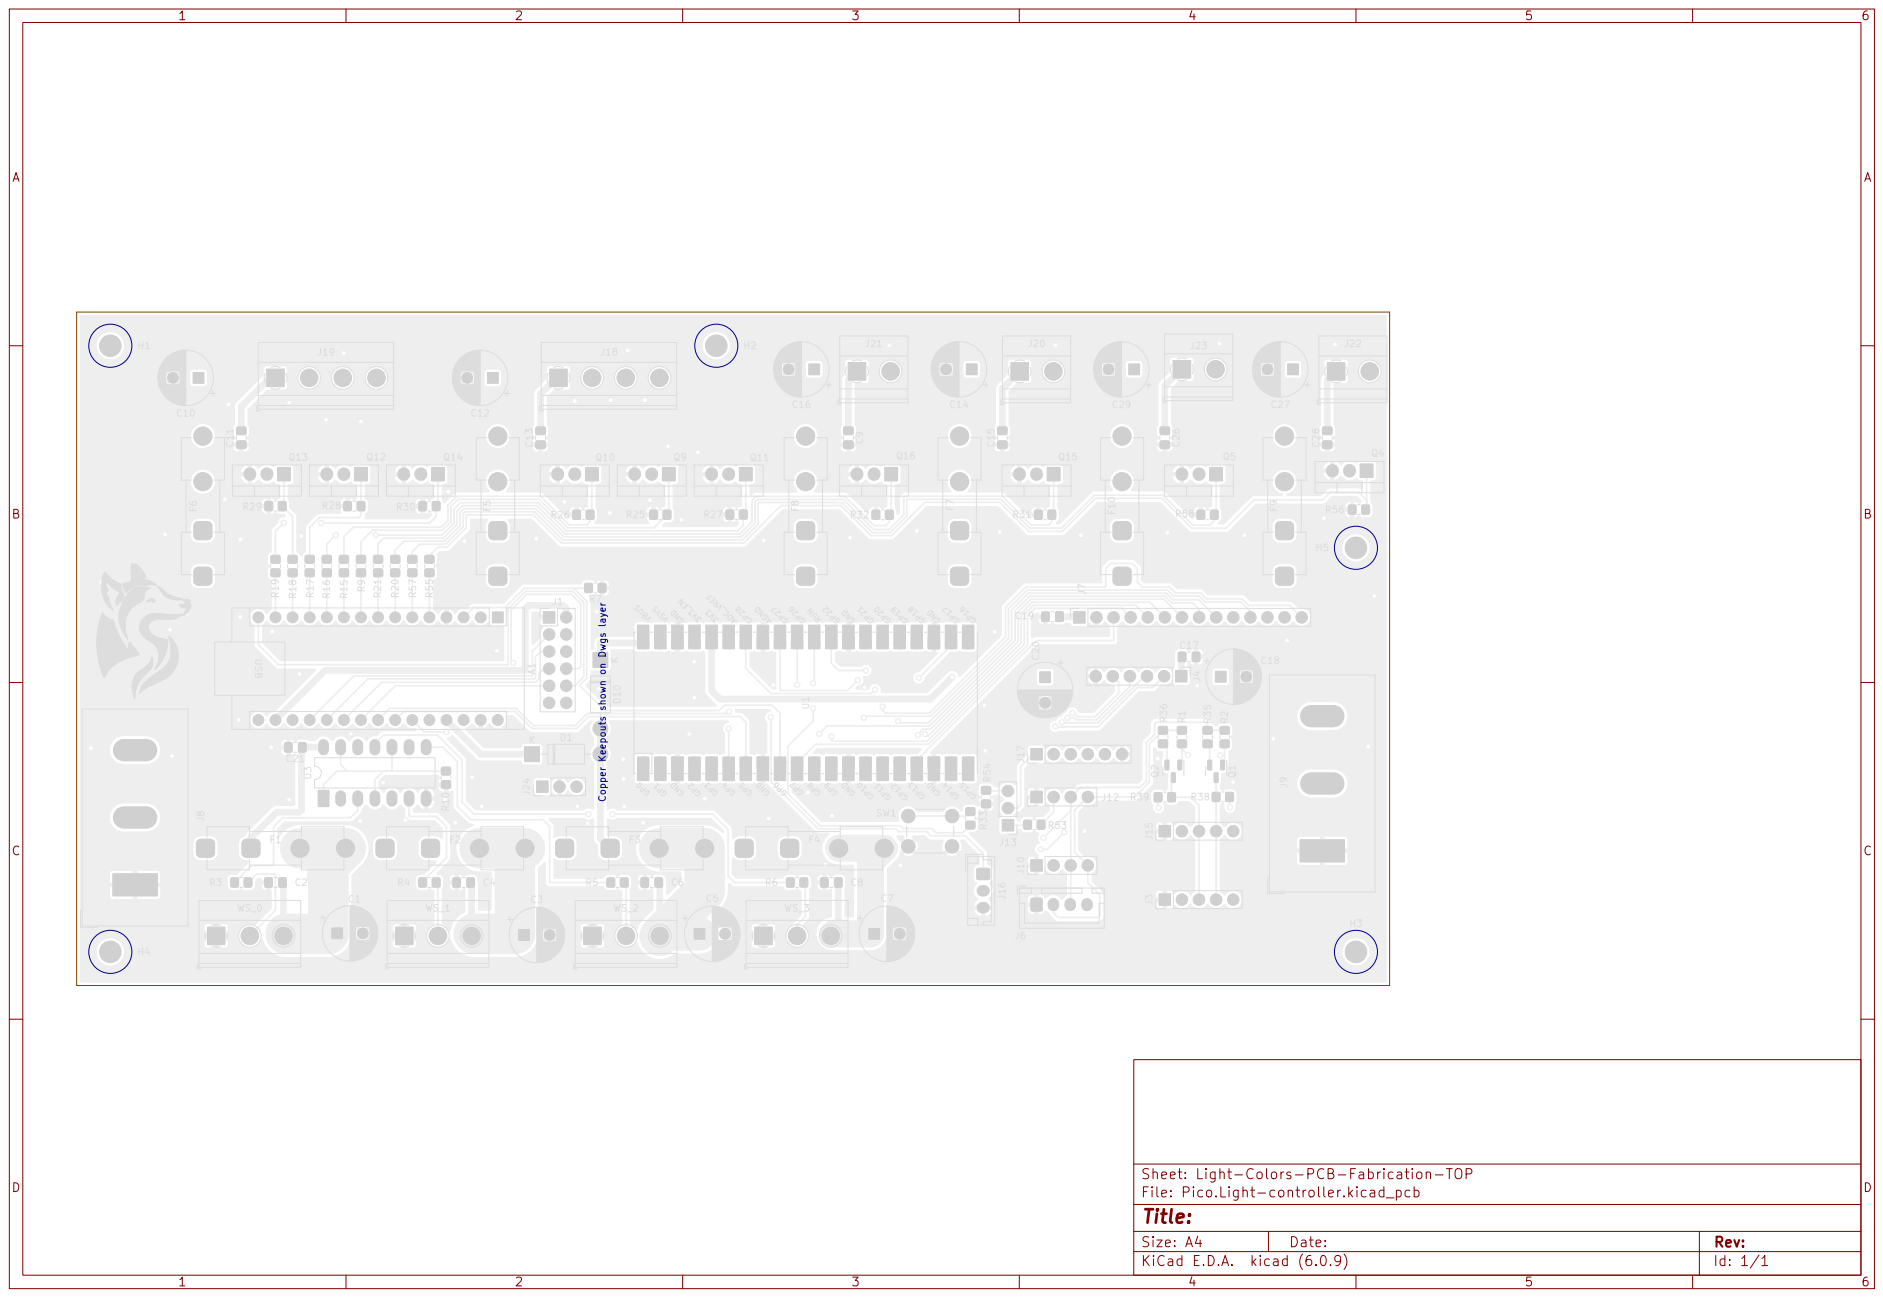
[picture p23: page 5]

ULC - PICO V3.0 universal Light Controller

Sheet: Light-Colors-PCB-Fabrication-TOP
File: Pico.Light-controller.kicad_pcb
Id: 1/1 Title:

A

A

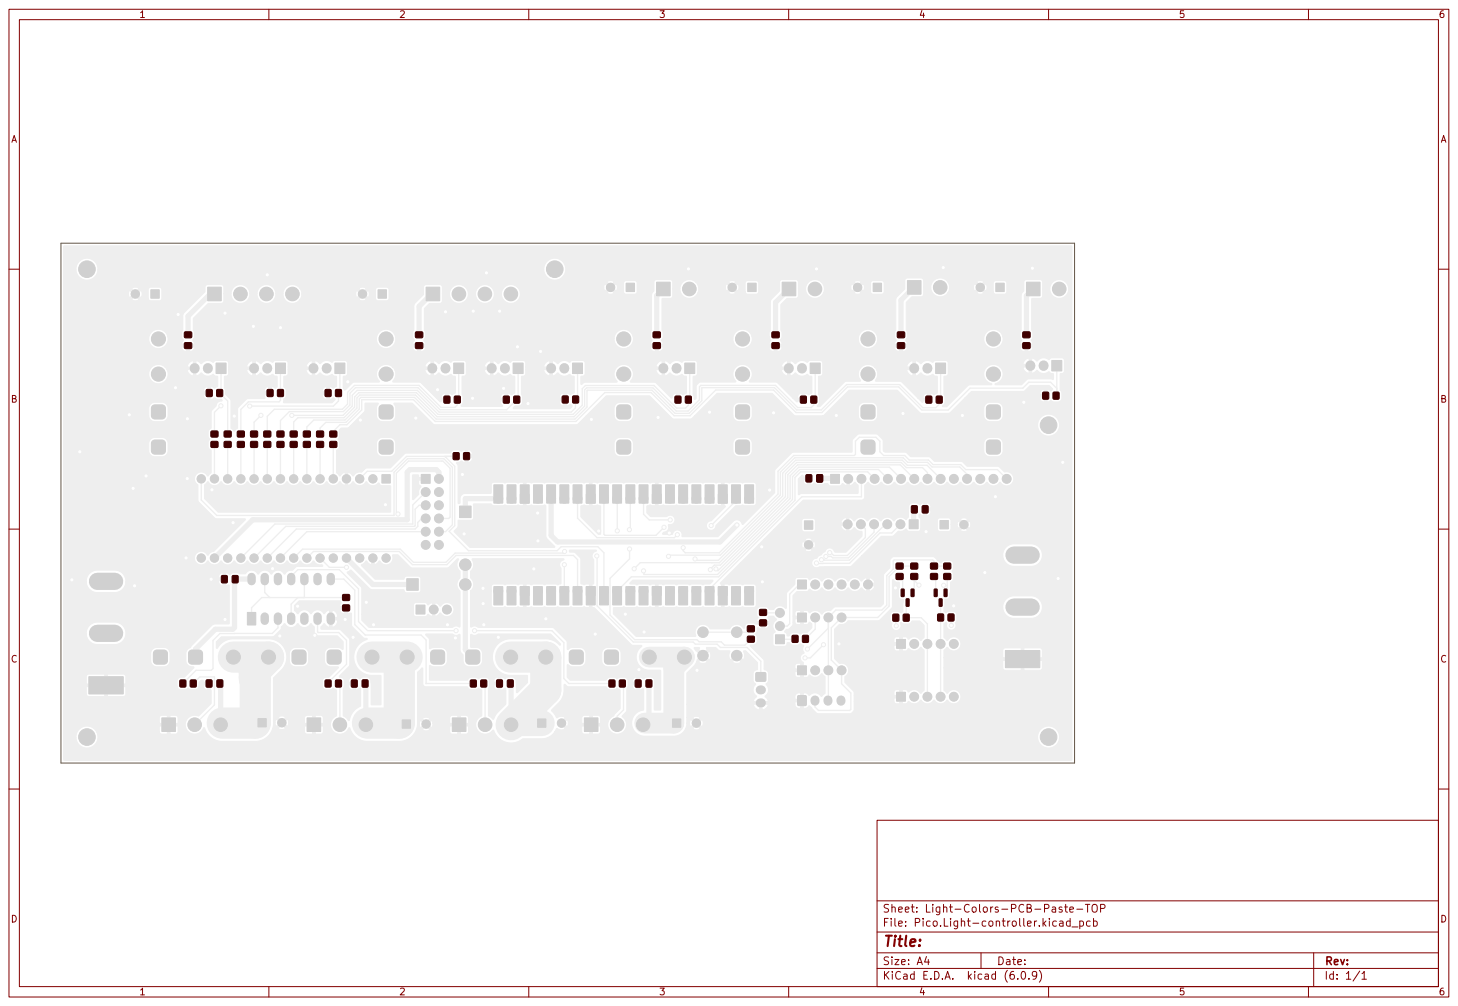
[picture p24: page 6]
D Date: KiCad E.D.A. kicad (6.0.9) Size: A4; Rev:

ULC - PICO V3.0 universal Light Controller

Sheet: Light-Colors-PCB-Paste-TOP
File: Pico.Light-controller.kicad_pcb
Id: 1/1 Title:

A

A

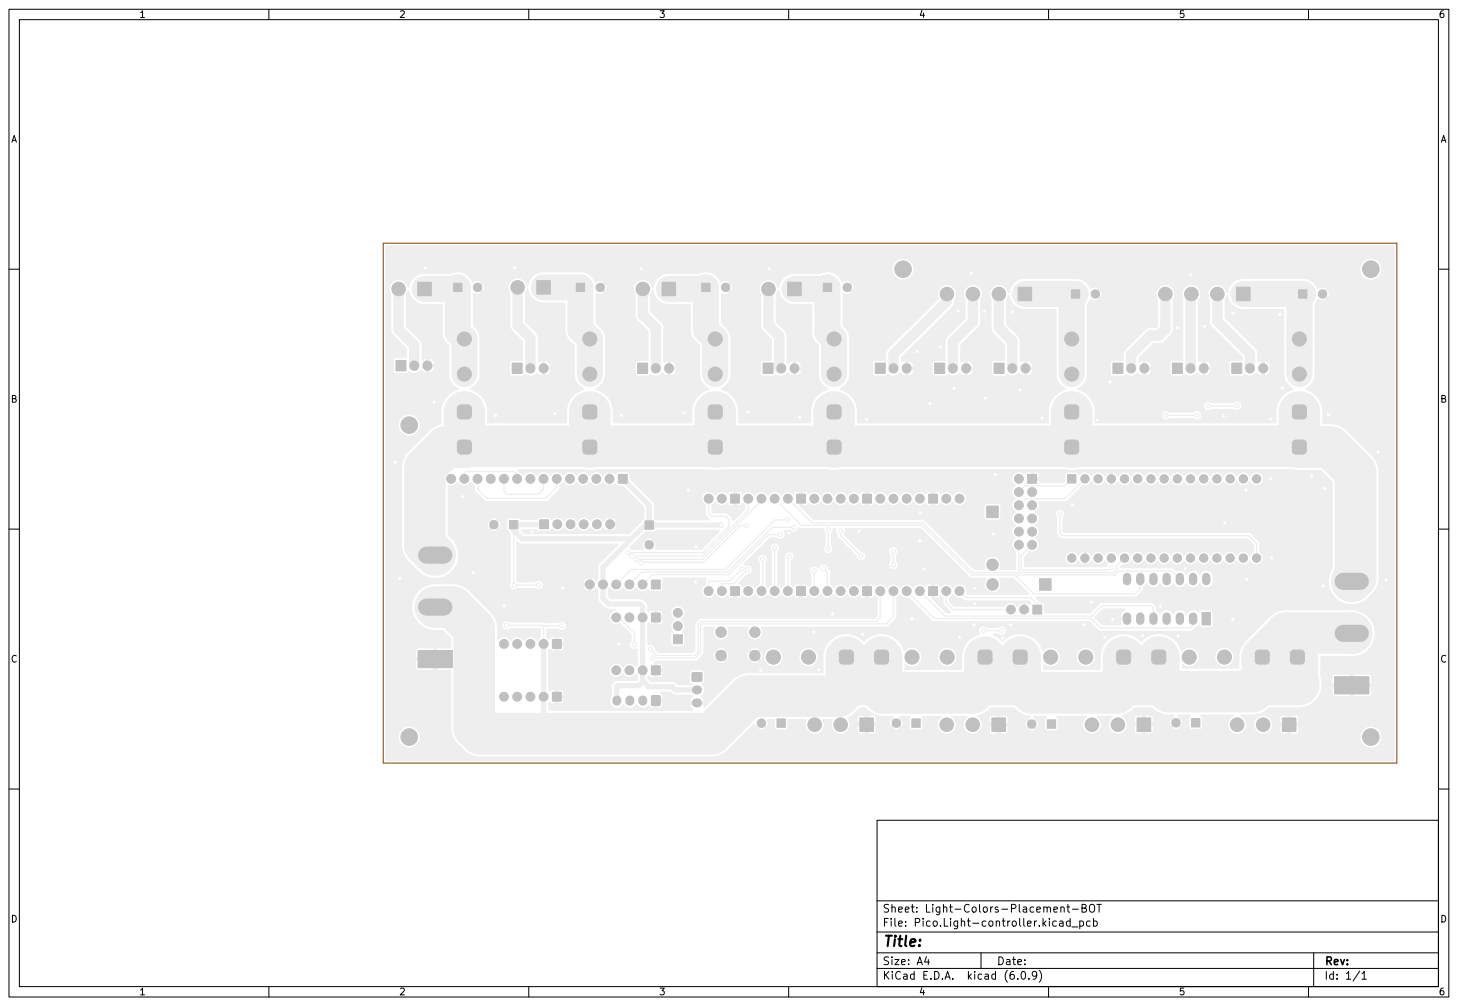
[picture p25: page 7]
D Date: KiCad E.D.A. kicad (6.0.9) Size: A4; Rev:

Sheet: Light-Colors-Placement-BOT
File: Pico.Light-controller.kicad_pcb
Id: 1/1 Title:

A

A

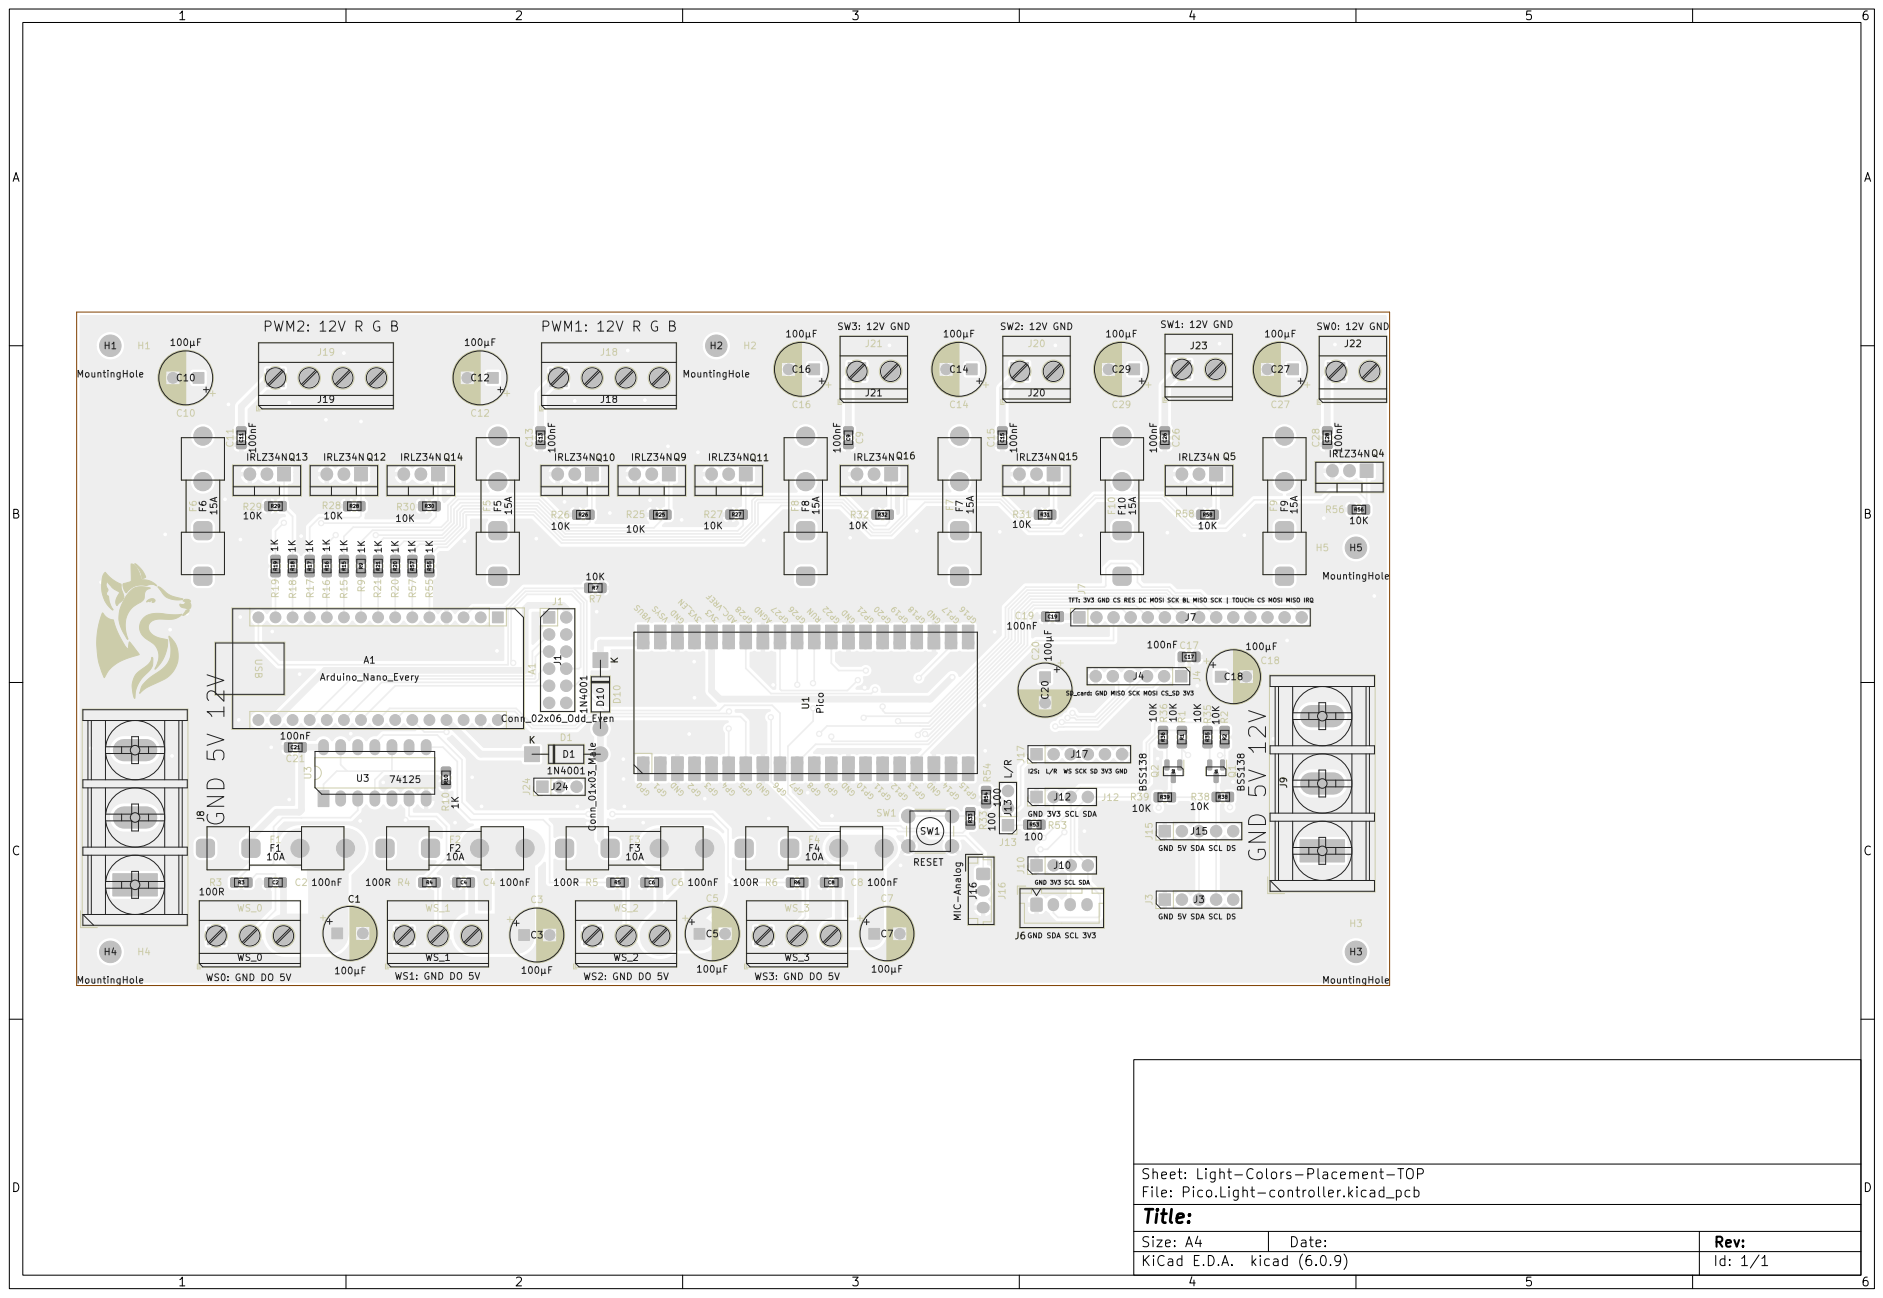
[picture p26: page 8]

ULC - PICO V3.0 universal Light Controller

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

R39 SD_card: GND MISO SCK MOSI CS_SD 3V3 J4 J8GND ⁵V ¹²V

I2S: L/R WS SCK SD 3V3 GND J17

Sheet: Light-Colors-Placement-TOP
File: Pico.Light-controller.kicad_pcb
Id: 1/1 Title:

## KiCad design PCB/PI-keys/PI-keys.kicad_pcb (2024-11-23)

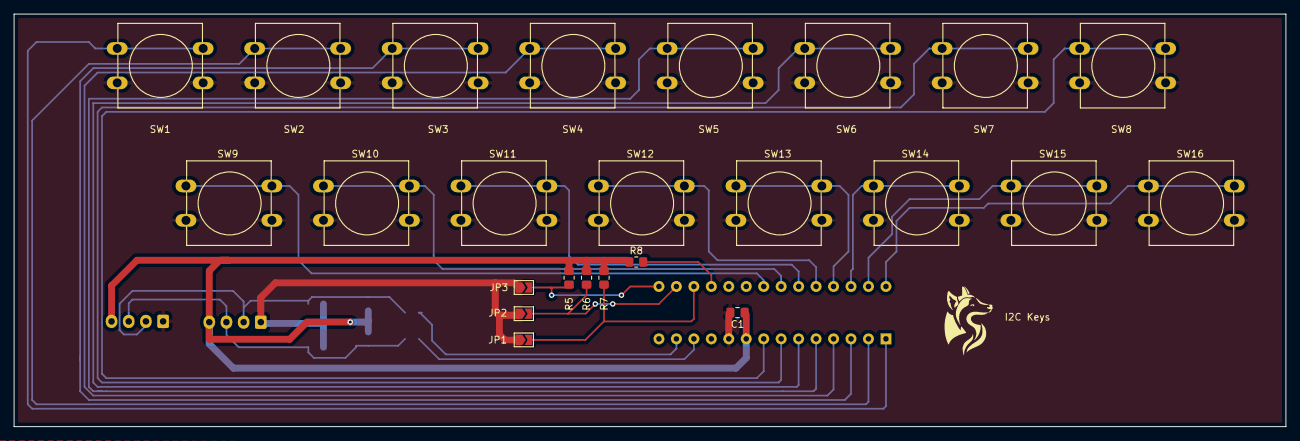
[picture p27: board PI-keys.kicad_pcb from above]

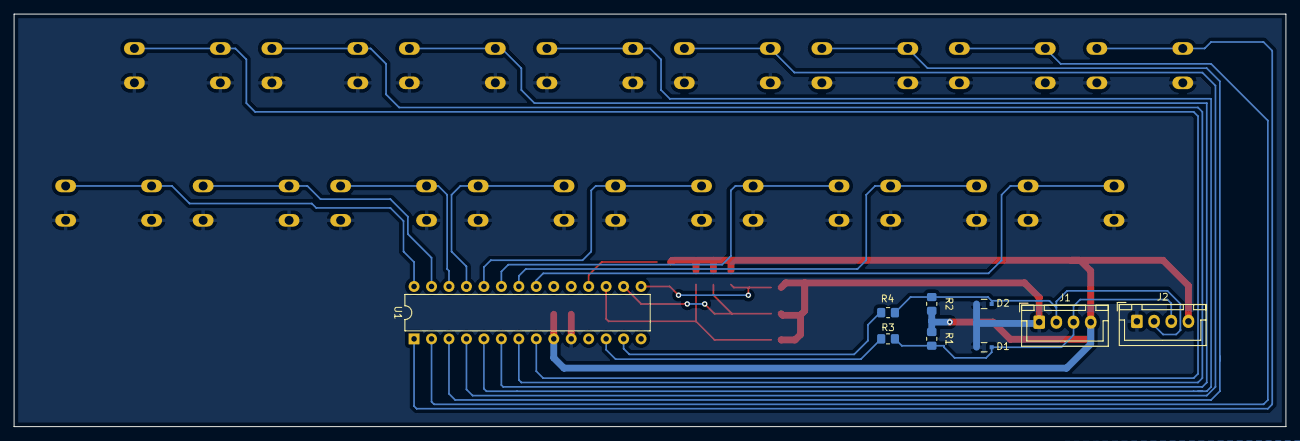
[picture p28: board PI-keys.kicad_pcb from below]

Board: 2 copper layers, 185.0 x 60.0 mm, 33 parts (9 on the bottom side), 26 nets.

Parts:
C1: 100nF; C_0805_2012Metric_Pad1.18x1.45mm_HandSolder
D1, D2: PESD5V0L1BA,115; Nexperia-SOD323-09_04_2018-0-0
J1, J2: Conn_01x04_Male; JST_XH_B4B-XH-A_1x04_P2.50mm_Vertical
JP1: A2; SolderJumper-2_P1.3mm_Open_TrianglePad1.0x1.5mm
JP2: A1; SolderJumper-2_P1.3mm_Open_TrianglePad1.0x1.5mm
JP3: A0; SolderJumper-2_P1.3mm_Open_TrianglePad1.0x1.5mm
R1, R2: 4K7; R_0805_2012Metric_Pad1.20x1.40mm_HandSolder
R3, R4: 0R; R_0805_2012Metric_Pad1.20x1.40mm_HandSolder
R5, R6, R7: 10K; R_0805_2012Metric_Pad1.20x1.40mm_HandSolder
R8: 100R; R_0805_2012Metric_Pad1.20x1.40mm_HandSolder
SW1, SW2, SW3, SW4, SW5, SW6, SW7, SW8, SW9, SW10, SW11, SW12, SW13, SW14, SW15, SW16: SW_Push_Dual; SW_PUSH-12mm
U1: MCP23017_SP; DIP-28_W7.62mm

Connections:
+3V3: C1.1, J1.4, J2.4, R1.1, R2.1, R5.1, R6.1, R7.1, R8.1, U1.9 (VDD)
GND: C1.2, D1.1, D2.1, J1.1, J2.1, JP1.1 (A), JP2.1 (A), JP3.1 (A), SW1.2, SW2.2, SW3.2, SW4.2, SW5.2, SW6.2, SW7.2, SW8.2, SW9.2, SW10.2, SW11.2, SW12.2, SW13.2, SW14.2, SW15.2, SW16.2, U1.10 (VSS)
unnamed: D1.2, J1.3, J2.3, R1.2, R3.2
unnamed: D2.2, J1.2, J2.2, R2.2, R4.2
unnamed: JP1.2 (B), R7.2, U1.17 (A2)
unnamed: JP2.2 (B), R6.2, U1.16 (A1)
unnamed: JP3.2 (B), R5.2, U1.15 (A0)
unnamed: R3.1, U1.12 (SCK)
unnamed: R4.1, U1.13 (SDA)
unnamed: SW1.1, U1.1 (GPB0)
unnamed: SW2.1, U1.2 (GPB1)
unnamed: SW3.1, U1.3 (GPB2)
unnamed: SW4.1, U1.4 (GPB3)
unnamed: SW5.1, U1.5 (GPB4)
unnamed: SW6.1, U1.6 (GPB5)
unnamed: SW7.1, U1.7 (GPB6)
unnamed: SW8.1, U1.8 (GPB7)
unnamed: SW9.1, U1.21 (GPA0)
unnamed: SW10.1, U1.22 (GPA1)
unnamed: SW11.1, U1.23 (GPA2)
unnamed: SW12.1, U1.24 (GPA3)
unnamed: SW13.1, U1.25 (GPA4)
unnamed: SW14.1, U1.26 (GPA5)
unnamed: SW15.1, U1.27 (GPA6)
unnamed: SW16.1, U1.28 (GPA7)
unnamed: R8.2, U1.18 (~RESET)

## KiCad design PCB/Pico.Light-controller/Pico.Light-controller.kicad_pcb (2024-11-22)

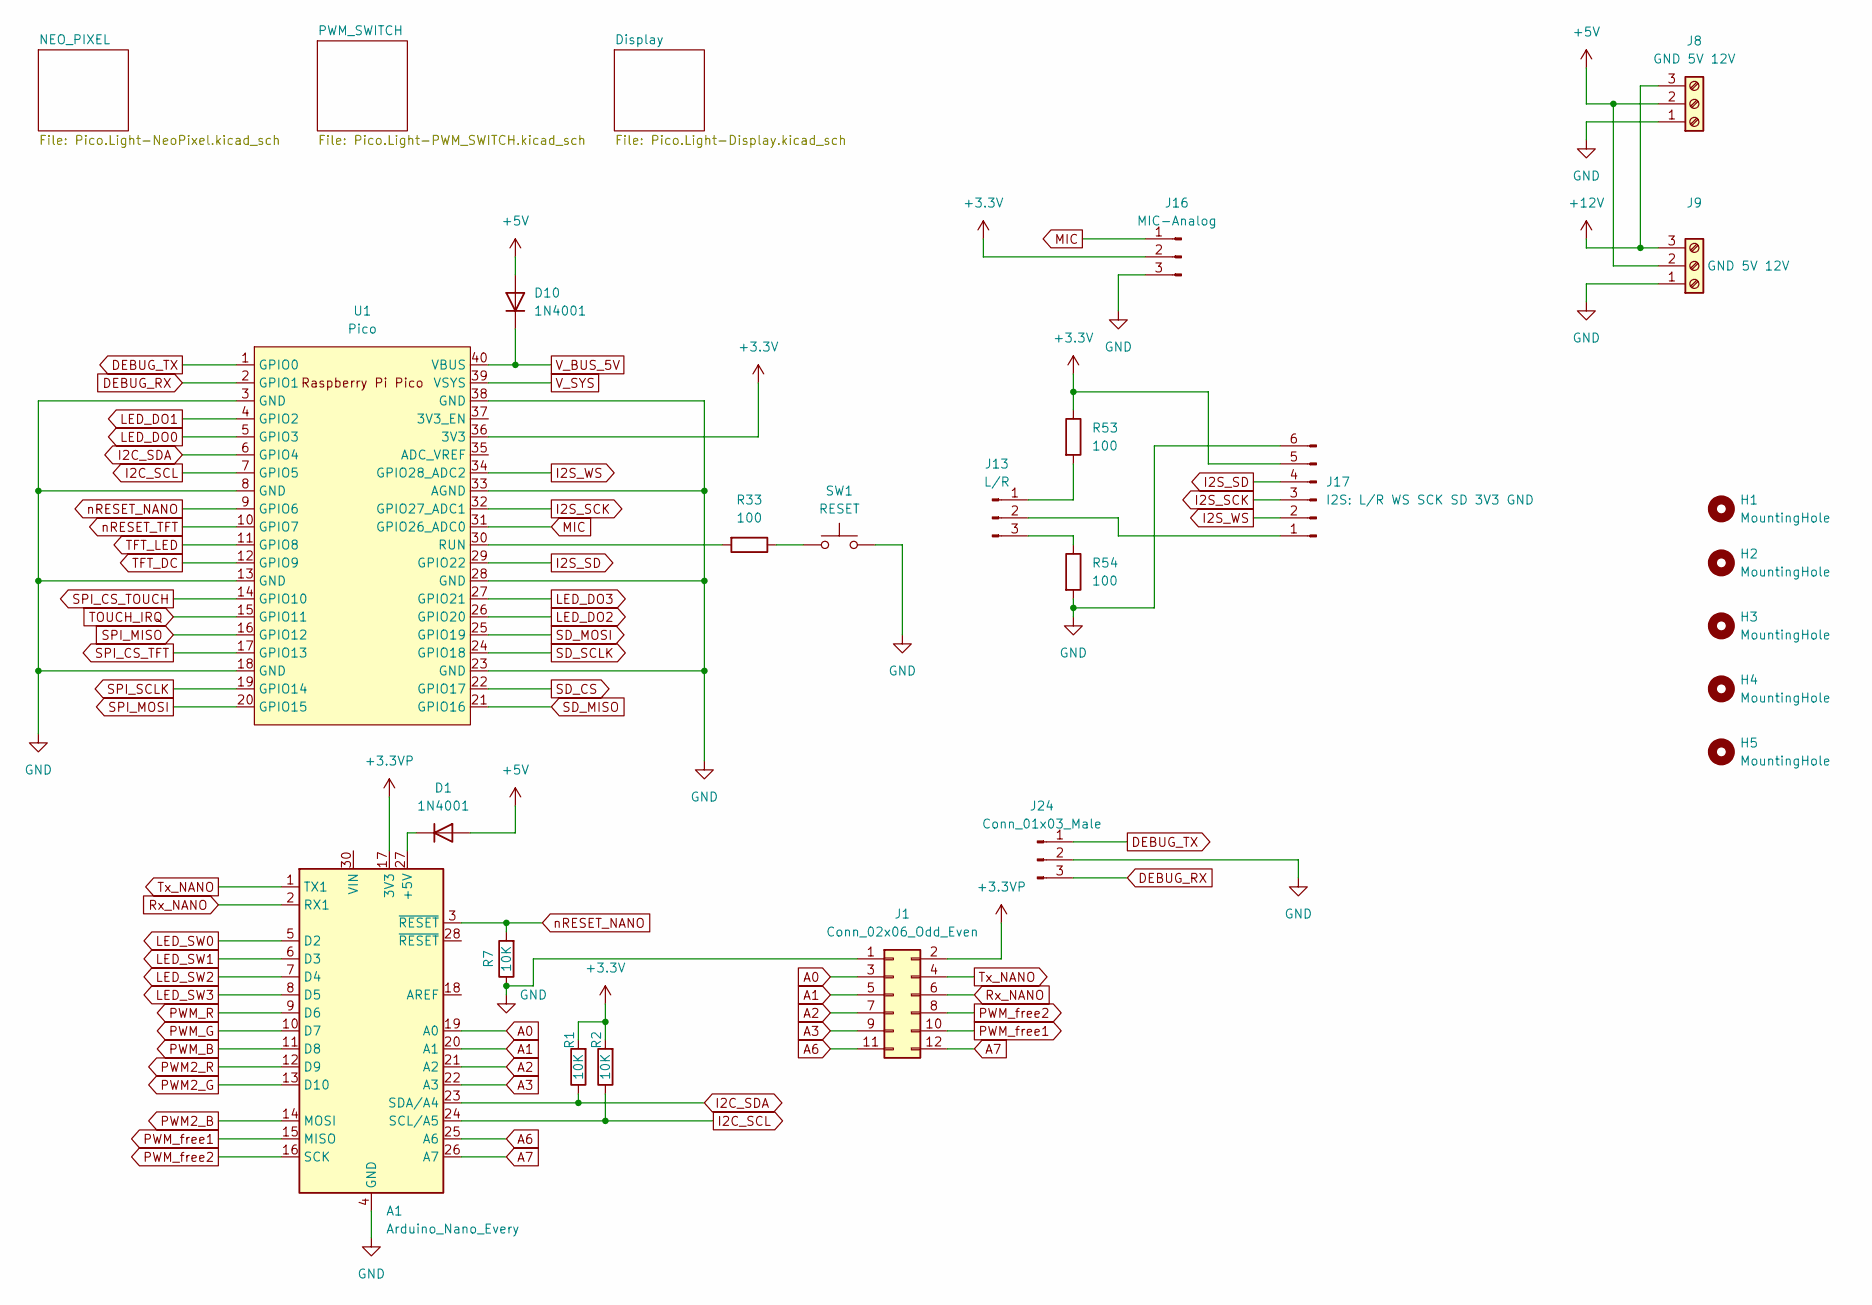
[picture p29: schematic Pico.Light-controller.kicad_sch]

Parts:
A1: Arduino_Nano_Every; Arduino_Nano
D1, D10: 1N4001; D_DO-41_SOD81_P10.16mm_Horizontal
H1, H2, H3, H4, H5: MountingHole; MountingHole_3.2mm_M3
J1: Conn_02x06_Odd_Even; PinHeader_2x06_P2.54mm_Vertical
J8, J9: GND 5V 12V; TerminalBlock_Dinkle_DT-55-B01X-03_P10.00mm
J13: L/R; PinHeader_1x03_P2.54mm_Vertical
J16: MIC-Analog; JST_EH_B3B-EH-A_1x03_P2.50mm_Vertical
J17: I2S: L/R WS SCK SD 3V3 GND; PinHeader_1x06_P2.54mm_Vertical
J24: Conn_01x03_Male; PinHeader_1x03_P2.54mm_Vertical
R1, R2, R7: 10K; R_0805_2012Metric_Pad1.20x1.40mm_HandSolder
R33, R53, R54: 100; R_0805_2012Metric_Pad1.20x1.40mm_HandSolder
SW1: RESET; SW_PUSH_6mm
U1: Pico; RPi_Pico_SMD_TH_Kopie

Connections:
+3.3V: J16.2, J17.5, R1.2, R2.2, R53.1, U1.36 (3V3); also elsewhere on the board
+3.3VP: A1.17 (3V3), J1.2
+5V: D1.2 (A), D10.2 (A), J8.2, J9.2; also elsewhere on the board
+12V: J8.3, J9.3; also elsewhere on the board
A0: A1.19 (A0), J1.3
A1: A1.20 (A1), J1.5
A2: A1.21 (A2), J1.7
A3: A1.22 (A3), J1.9
A6: A1.25 (A6), J1.11
A7: A1.26 (A7), J1.12
DEBUG_RX: J24.3, U1.2 (GPIO1)
DEBUG_TX: J24.1, U1.1 (GPIO0)
GND: A1.4 (GND), A1.29 (GND), J1.1, J8.1, J9.1, J16.3, J17.6, J24.2, R7.1, R54.2, SW1.2, U1.3 (GND), U1.8 (GND), U1.13 (GND), U1.18 (GND), U1.23 (GND), U1.28 (GND), U1.33 (AGND), U1.38 (GND); also elsewhere on the board
I2C_SCL: A1.24 (SCL/A5), R2.1, U1.7 (GPIO5); also elsewhere on the board
I2C_SDA: A1.23 (SDA/A4), R1.1, U1.6 (GPIO4); also elsewhere on the board
I2S_SCK: J17.3, U1.32 (GPIO27_ADC1)
I2S_SD: J17.4, U1.29 (GPIO22)
I2S_WS: J17.2, U1.34 (GPIO28_ADC2)
LED_DO0: U1.5 (GPIO3); also elsewhere on the board
LED_DO1: U1.4 (GPIO2); also elsewhere on the board
LED_DO2: U1.26 (GPIO20); also elsewhere on the board
LED_DO3: U1.27 (GPIO21); also elsewhere on the board
LED_SW0: A1.5 (D2); also elsewhere on the board
LED_SW1: A1.6 (D3); also elsewhere on the board
LED_SW2: A1.7 (D4); also elsewhere on the board
LED_SW3: A1.8 (D5); also elsewhere on the board
MIC: J16.1, U1.31 (GPIO26_ADC0)
unnamed: A1.27 (+5V), D1.1 (K)
unnamed: J13.1, R53.2
unnamed: J13.2, J17.1
unnamed: J13.3, R54.1
unnamed: R33.1, SW1.1
unnamed: R33.2, U1.30 (RUN)
PWM2_B: A1.14 (MOSI); also elsewhere on the board
PWM2_G: A1.13 (D10); also elsewhere on the board
PWM2_R: A1.12 (D9); also elsewhere on the board
PWM_B: A1.11 (D8); also elsewhere on the board
PWM_G: A1.10 (D7); also elsewhere on the board
PWM_R: A1.9 (D6); also elsewhere on the board
PWM_free1: A1.15 (MISO), J1.10
PWM_free2: A1.16 (SCK), J1.8
Rx_NANO: A1.2 (RX1), J1.6
SD_CS: U1.22 (GPIO17); also elsewhere on the board
SD_MISO: U1.21 (GPIO16); also elsewhere on the board
SD_MOSI: U1.25 (GPIO19); also elsewhere on the board
SD_SCLK: U1.24 (GPIO18); also elsewhere on the board
SPI_CS_TFT: U1.17 (GPIO13); also elsewhere on the board
SPI_CS_TOUCH: U1.14 (GPIO10); also elsewhere on the board
SPI_MISO: U1.16 (GPIO12); also elsewhere on the board
SPI_MOSI: U1.20 (GPIO15); also elsewhere on the board
SPI_SCLK: U1.19 (GPIO14); also elsewhere on the board
TFT_DC: U1.12 (GPIO9); also elsewhere on the board
TFT_LED: U1.11 (GPIO8); also elsewhere on the board
TOUCH_IRQ: U1.15 (GPIO11); also elsewhere on the board
Tx_NANO: A1.1 (TX1), J1.4
V_BUS_5V: D10.1 (K), U1.40 (VBUS)
V_SYS: U1.39 (VSYS)
nRESET_NANO: A1.3 (~RESET), R7.2, U1.9 (GPIO6)
nRESET_TFT: U1.10 (GPIO7); also elsewhere on the board

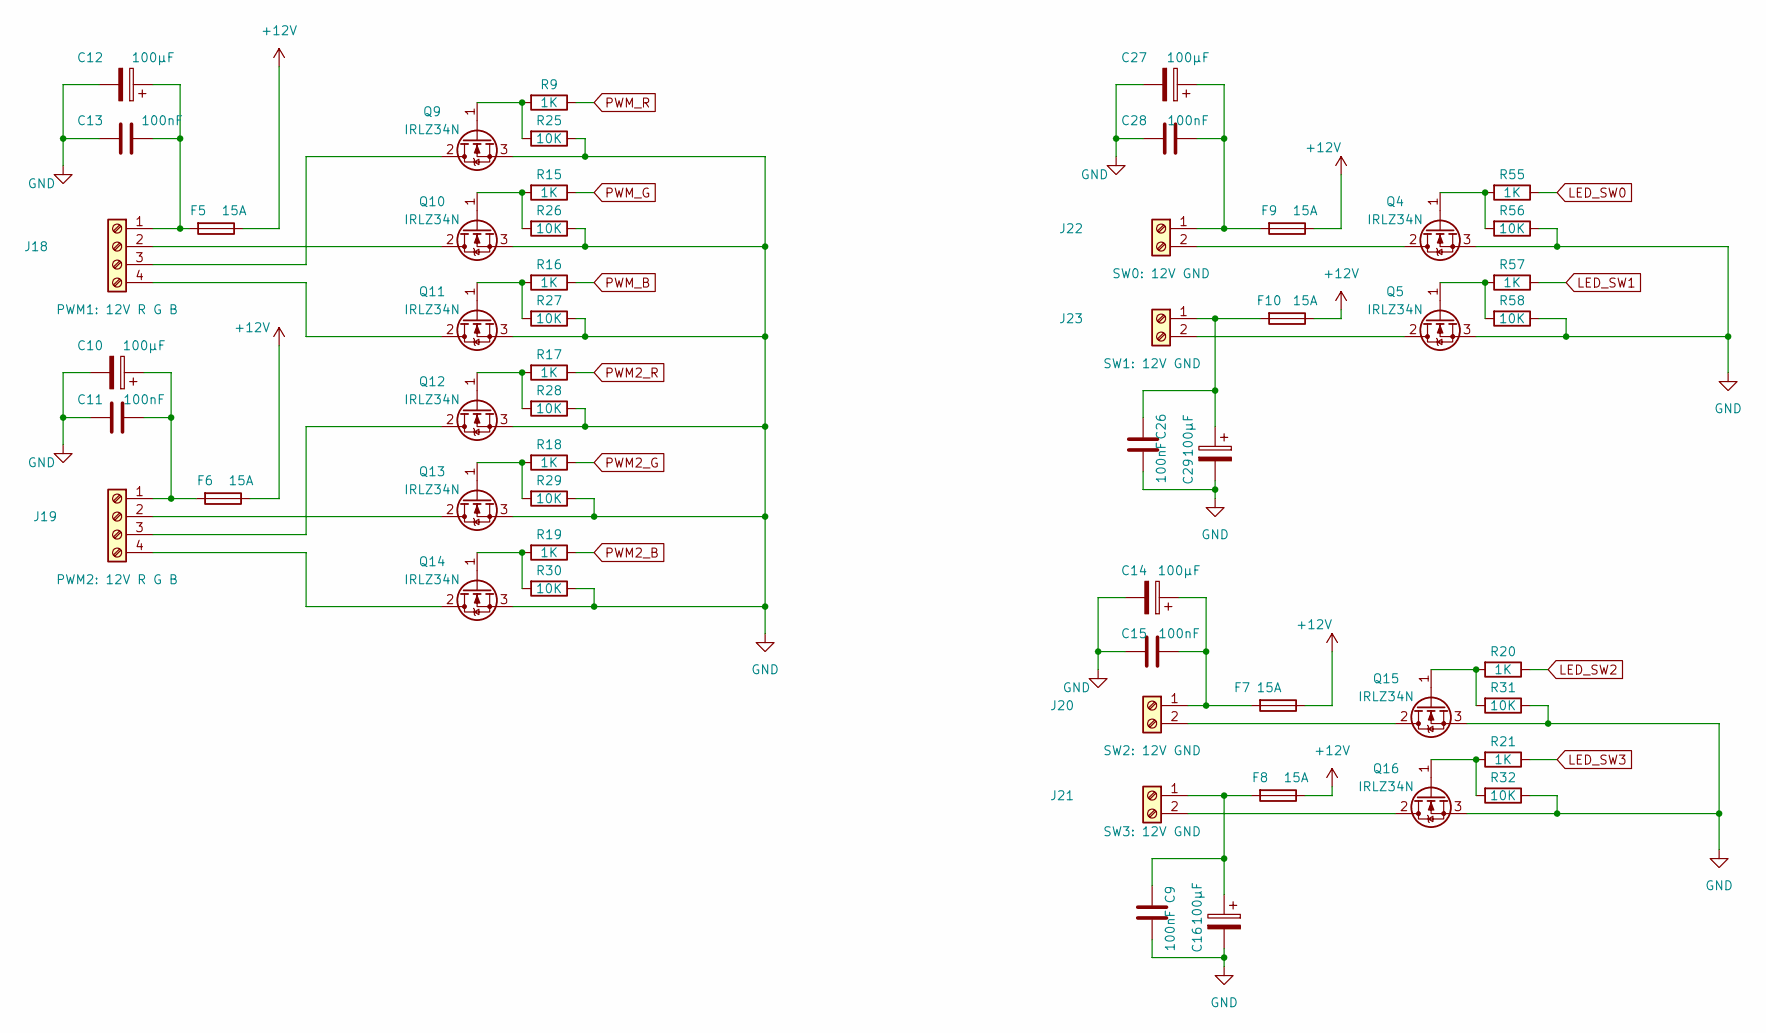
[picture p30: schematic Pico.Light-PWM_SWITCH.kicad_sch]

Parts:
C9, C11, C13, C15, C26, C28: 100nF; C_0805_2012Metric_Pad1.18x1.45mm_HandSolder
C10, C12, C14, C16, C27, C29: 100µF; CP_Radial_D8.0mm_P3.80mm
F5, F6, F7, F8, F9, F10: 15A; Fuseholder_Clip-5x20mm_Eaton_1A5601-01_Inline_P20.80x6.76mm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
J18: PWM1: 12V R G B; TerminalBlock_Phoenix_MKDS-1,5-4_1x04_P5.00mm_Horizontal
J19: PWM2: 12V R G B; TerminalBlock_Phoenix_MKDS-1,5-4_1x04_P5.00mm_Horizontal
J20: SW2: 12V GND; TerminalBlock_Phoenix_MKDS-1,5-2_1x02_P5.00mm_Horizontal
J21: SW3: 12V GND; TerminalBlock_Phoenix_MKDS-1,5-2_1x02_P5.00mm_Horizontal
J22: SW0: 12V GND; TerminalBlock_Phoenix_MKDS-1,5-2_1x02_P5.00mm_Horizontal
J23: SW1: 12V GND; TerminalBlock_Phoenix_MKDS-1,5-2_1x02_P5.00mm_Horizontal
Q4, Q5, Q9, Q10, Q11, Q12, Q13, Q14, Q15, Q16: IRLZ34N; TO-220-3_Vertical
R9, R15, R16, R17, R18, R19, R20, R21, R55, R57: 1K; R_0805_2012Metric_Pad1.20x1.40mm_HandSolder
R25, R26, R27, R28, R29, R30, R31, R32, R56, R58: 10K; R_0805_2012Metric_Pad1.20x1.40mm_HandSolder

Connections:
+12V: F5.1, F6.1, F7.1, F8.1, F9.1, F10.1; also elsewhere on the board
GND: C9.2, C10.2, C11.1, C12.2, C13.1, C14.2, C15.1, C16.2, C26.2, C27.2, C28.1, C29.2, Q4.3 (S), Q5.3 (S), Q9.3 (S), Q10.3 (S), Q11.3 (S), Q12.3 (S), Q13.3 (S), Q14.3 (S), Q15.3 (S), Q16.3 (S), R25.1, R26.1, R27.1, R28.1, R29.1, R30.1, R31.1, R32.1, R56.1, R58.1; also elsewhere on the board
LED_SW0: R55.1; also elsewhere on the board
LED_SW1: R57.1; also elsewhere on the board
LED_SW2: R20.1; also elsewhere on the board
LED_SW3: R21.1; also elsewhere on the board
unnamed: C10.1, C11.2, F6.2, J19.1
unnamed: C12.1, C13.2, F5.2, J18.1
unnamed: C14.1, C15.2, F7.2, J20.1
unnamed: C9.1, C16.1, F8.2, J21.1
unnamed: C26.1, C29.1, F10.2, J23.1
unnamed: C27.1, C28.2, F9.2, J22.1
unnamed: J18.2, Q10.2 (D)
unnamed: J18.3, Q9.2 (D)
unnamed: J18.4, Q11.2 (D)
unnamed: J19.2, Q13.2 (D)
unnamed: J19.3, Q12.2 (D)
unnamed: J19.4, Q14.2 (D)
unnamed: J20.2, Q15.2 (D)
unnamed: J21.2, Q16.2 (D)
unnamed: J22.2, Q4.2 (D)
unnamed: J23.2, Q5.2 (D)
unnamed: Q4.1 (G), R55.2, R56.2
unnamed: Q5.1 (G), R57.2, R58.2
unnamed: Q9.1 (G), R9.2, R25.2
unnamed: Q10.1 (G), R15.2, R26.2
unnamed: Q11.1 (G), R16.2, R27.2
unnamed: Q12.1 (G), R17.2, R28.2
unnamed: Q13.1 (G), R18.2, R29.2
unnamed: Q14.1 (G), R19.2, R30.2
unnamed: Q15.1 (G), R20.2, R31.2
unnamed: Q16.1 (G), R21.2, R32.2
PWM2_B: R19.1; also elsewhere on the board
PWM2_G: R18.1; also elsewhere on the board
PWM2_R: R17.1; also elsewhere on the board
PWM_B: R16.1; also elsewhere on the board
PWM_G: R15.1; also elsewhere on the board
PWM_R: R9.1; also elsewhere on the board

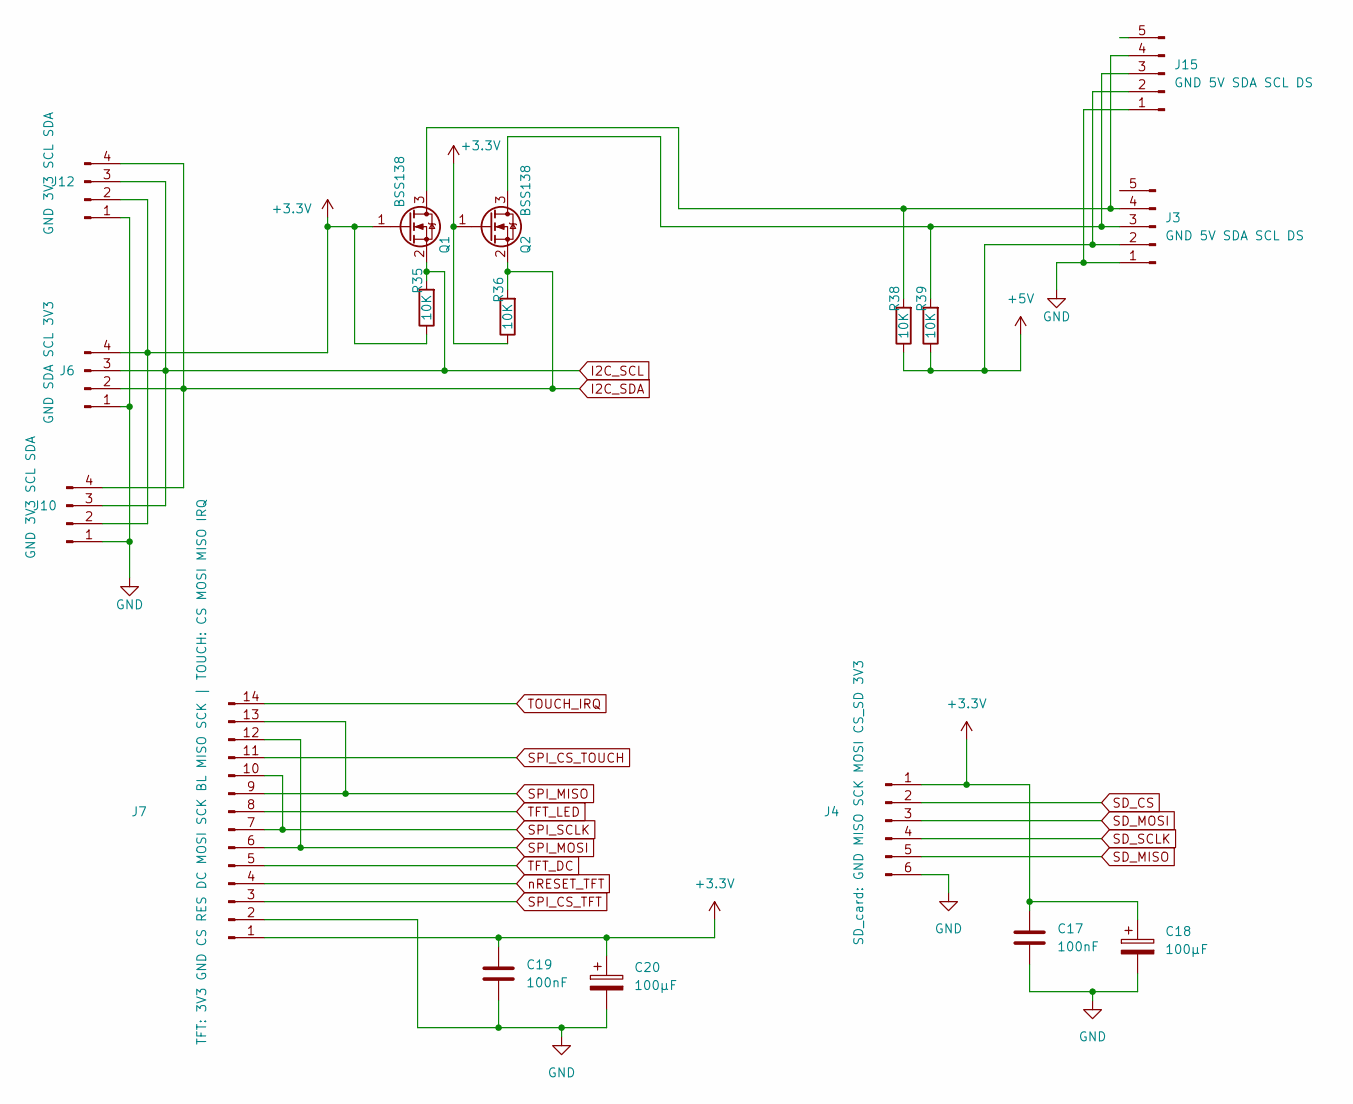
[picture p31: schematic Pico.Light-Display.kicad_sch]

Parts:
C17, C19: 100nF; C_0805_2012Metric_Pad1.18x1.45mm_HandSolder
C18, C20: 100µF; CP_Radial_D8.0mm_P3.80mm
J3, J15: GND 5V SDA SCL DS; PinHeader_1x05_P2.54mm_Vertical
J4: SD_card: GND MISO SCK MOSI CS_SD 3V3; PinHeader_1x06_P2.54mm_Vertical
J6: GND SDA SCL 3V3; JST_XH_B4B-XH-A_1x04_P2.50mm_Vertical
J7: TFT: 3V3 GND CS RES DC MOSI SCK BL MISO SCK | TOU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; PinSocket_1x14_P2.54mm_Vertical
J10, J12: GND 3V3 SCL SDA; PinHeader_1x04_P2.54mm_Vertical
Q1, Q2: BSS138; SOT-23
R35, R36, R38, R39: 10K; R_0805_2012Metric_Pad1.20x1.40mm_HandSolder

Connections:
+3.3V: C17.1, C18.1, C19.1, C20.1, J4.1, J6.4, J7.1, J10.2, J12.2, Q1.1 (G), Q2.1 (G), R35.1, R36.1; also elsewhere on the board
+5V: J3.2, J15.2, R38.1, R39.1; also elsewhere on the board
GND: C17.2, C18.2, C19.2, C20.2, J3.1, J4.6, J6.1, J7.2, J10.1, J12.1, J15.1; also elsewhere on the board
I2C_SCL: J6.3, J10.3, J12.3, Q1.2 (S), R35.2; also elsewhere on the board
I2C_SDA: J6.2, J10.4, J12.4, Q2.2 (S), R36.2; also elsewhere on the board
unnamed: J3.3, J15.3, Q2.3 (D), R39.2
unnamed: J3.4, J15.4, Q1.3 (D), R38.2
SD_CS: J4.2; also elsewhere on the board
SD_MISO: J4.5; also elsewhere on the board
SD_MOSI: J4.3; also elsewhere on the board
SD_SCLK: J4.4; also elsewhere on the board
SPI_CS_TFT: J7.3; also elsewhere on the board
SPI_CS_TOUCH: J7.11; also elsewhere on the board
SPI_MISO: J7.9, J7.13; also elsewhere on the board
SPI_MOSI: J7.6, J7.12; also elsewhere on the board
SPI_SCLK: J7.7, J7.10; also elsewhere on the board
TFT_DC: J7.5; also elsewhere on the board
TFT_LED: J7.8; also elsewhere on the board
TOUCH_IRQ: J7.14; also elsewhere on the board
nRESET_TFT: J7.4; also elsewhere on the board

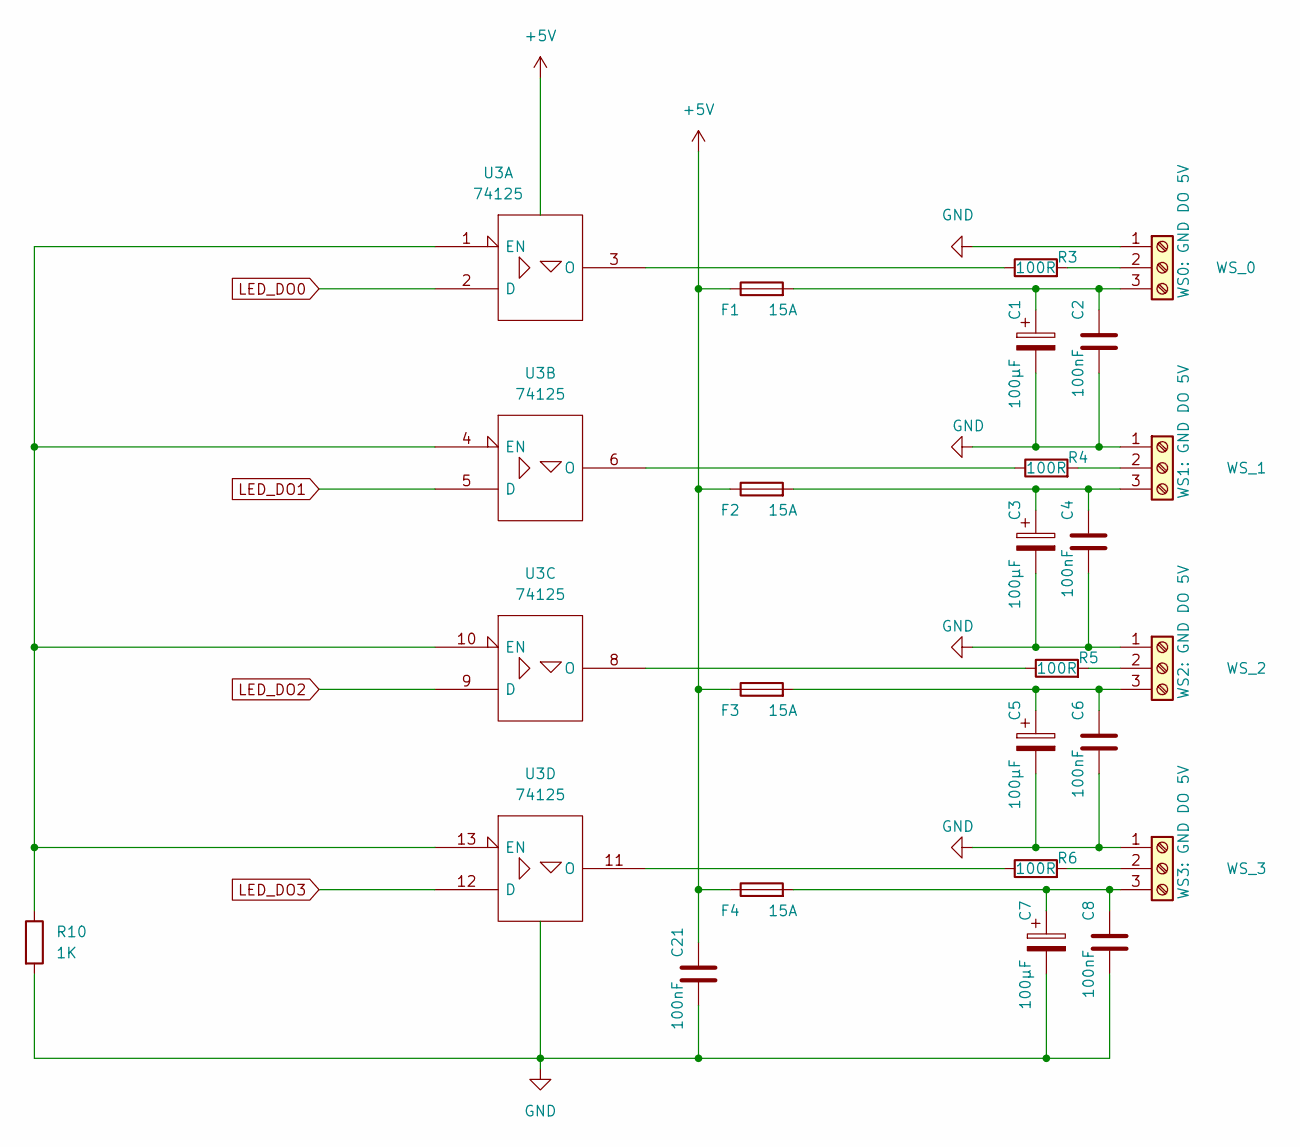
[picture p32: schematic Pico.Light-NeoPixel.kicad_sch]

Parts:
C1, C3, C5, C7: 100µF; CP_Radial_D8.0mm_P3.80mm
C2, C4, C6, C8, C21: 100nF; C_0805_2012Metric_Pad1.18x1.45mm_HandSolder
F1, F2, F3, F4: 15A; Fuseholder_Clip-5x20mm_Eaton_1A5601-01_Inline_P20.80x6.76mm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
R3, R4, R5, R6: 100R; R_0805_2012Metric_Pad1.20x1.40mm_HandSolder
R10: 1K; R_0805_2012Metric_Pad1.20x1.40mm_HandSolder
U3: 74125; DIP-14_W7.62mm_LongPads
WS_0: WS0: GND DO 5V; TerminalBlock_Phoenix_MKDS-1,5-3_1x03_P5.00mm_Horizontal
WS_1: WS1: GND DO 5V; TerminalBlock_Phoenix_MKDS-1,5-3_1x03_P5.00mm_Horizontal
WS_2: WS2: GND DO 5V; TerminalBlock_Phoenix_MKDS-1,5-3_1x03_P5.00mm_Horizontal
WS_3: WS3: GND DO 5V; TerminalBlock_Phoenix_MKDS-1,5-3_1x03_P5.00mm_Horizontal

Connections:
+5V: C21.1, F1.1, F2.1, F3.1, F4.1, U3.14 (VCC); also elsewhere on the board
GND: C1.2, C2.2, C3.2, C4.2, C5.2, C6.2, C7.2, C8.2, C21.2, R10.2, U3.7 (GND), WS_0.1, WS_1.1, WS_2.1, WS_3.1; also elsewhere on the board
LED_DO0: U3.2 (D); also elsewhere on the board
LED_DO1: U3.5 (D); also elsewhere on the board
LED_DO2: U3.9 (D); also elsewhere on the board
LED_DO3: U3.12 (D); also elsewhere on the board
unnamed: C1.1, C2.1, F1.2, WS_0.3
unnamed: C3.1, C4.1, F2.2, WS_1.3
unnamed: C5.1, C6.1, F3.2, WS_2.3
unnamed: C7.1, C8.1, F4.2, WS_3.3
unnamed: R3.1, U3.3 (O)
unnamed: R3.2, WS_0.2
unnamed: R4.1, U3.6 (O)
unnamed: R4.2, WS_1.2
unnamed: R5.1, U3.8 (O)
unnamed: R5.2, WS_2.2
unnamed: R6.1, U3.11 (O)
unnamed: R6.2, WS_3.2
unnamed: R10.1, U3.1 (EN), U3.4 (EN), U3.10 (EN), U3.13 (EN)

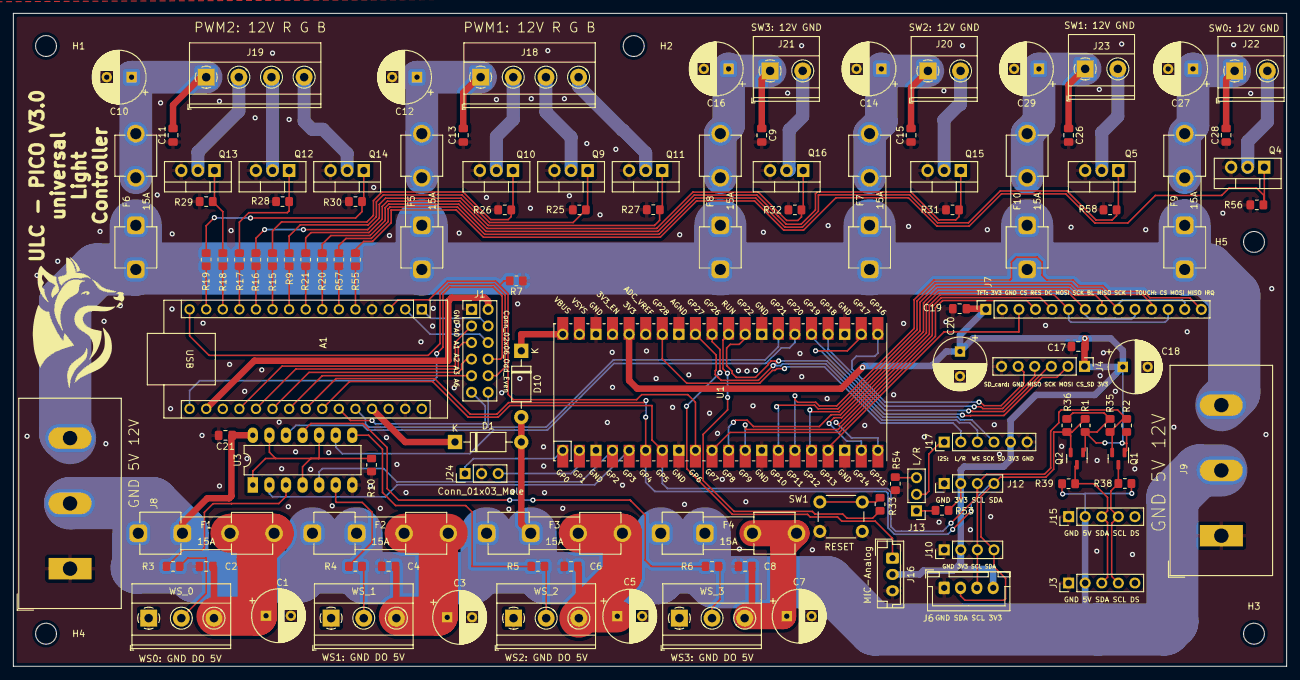
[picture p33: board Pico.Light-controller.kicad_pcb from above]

Board: 2 copper layers, 195.0 x 100.0 mm, 117 parts (0 on the bottom side), 99 nets.

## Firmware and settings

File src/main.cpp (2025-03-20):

/*
 * MIT License
 * 
 * Copyright (c) 2024 MonkeyCodeMen@GitHub
 * 
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
 * THE SOFTWARE IS PROVIDED "AS IS", WITHOUT WARRANTY OF ANY KIND, EXPRESS OR
 * IMPLIED, INCLUDING BUT NOT LIMITED TO THE WARRANTIES OF MERCHANTABILITY,
 * FITNESS FOR A PARTICULAR PURPOSE AND NONINFRINGEMENT. IN NO EVENT SHALL THE
 * AUTHORS OR COPYRIGHT HOLDERS BE LIABLE FOR ANY CLAIM, DAMAGES OR OTHER
 * LIABILITY, WHETHER IN AN ACTION OF CONTRACT, TORT OR OTHERWISE, ARISING FROM,
 * OUT OF OR IN CONNECTION WITH THE SOFTWARE OR THE USE OR OTHER DEALINGS IN THE
 * SOFTWARE.
 */


#include <Arduino.h>
#include <MainConfig.h>
#include <PinMapping.h>
#include <Blink.hpp>

#include <SPI.h>
#include <Debug.hpp>
#include <helper.h>

#include <LedObjects.hpp>
#include <Menu.hpp>

#include <LoopStats.hpp>
#include <Com.hpp>
#include <keyboard.hpp>
#include <Resources.hpp>

#include <I2C_master.hpp>
#include <I2C_register.h>

#include <Display.hpp>
#include <SDcard.hpp>
#include <BufferedClock.hpp>

#include <configCollection.hpp>

/*****************************************************************
 * 
 *    ToDo'S / aufräumen
 * 
 ******************************************************************
  + use AniCfg in hotkey / scenario 
  + make bakup (and read back) of last setup data .. how to deal with binary data ?
  + implement startup test mode
  + implement boot screen
  + add new second class functionality with reset or not  ????
  + exchange JSON config by YAML
 */




/*****************************************************************
 * 
 *    VAR's
 * 
 ******************************************************************
 */

volatile bool setupStartsecondCore = false;   // false:  first core0 setup .. then core1 setup      || true: core0 and core1 setup in parallel
volatile bool waitForsecondCore    = true;    // false:  core0 starts with loop directly after setup|| true: core0 waits for core1 to finish setup first, then start loop

BlinkingLED blink(LED_BUILTIN);

// menuCtrlEntries  ist the selection of connected CTRL objects in the menus
typedef MenuEntryList* MenuEntryListPtr;
MenuEntryListPtr menuCtrlEntries[CTRL_OBJECT_COUNT] = {&menuMainSwitch1,&menuMainSwitch2,&menuMainSwitch3,&menuMainSwitch4,
                                                      &menuMainRGB1,&menuMainRGB2,&menuMainNeo1,&menuMainNeo2,
                                                      &menuMainMatrix1,&menuMainMatrix2};



/*****************************************************************
 * 
 *    functions
 * 
 ******************************************************************
 */

void mainMenu_syncToCtrl(){
  int nrMenu,nrCtrl;
  for(int i=0;i<CTRL_OBJECT_COUNT;i++){
    nrMenu = menuCtrlEntries[i]->getIndex();
    nrCtrl = ctrlObjectList[i]->getNr();
    if ((nrMenu >= 0) && (nrCtrl != nrMenu)){
      ctrlObjectList[i]->select(nrMenu);
    }
  }
}

void mainMenu_syncFromCtrl(){
  int nr;
  for(int i=0;i<CTRL_OBJECT_COUNT;i++){
    nr = ctrlObjectList[i]->getNr();
    if (nr >= 0){
      menuCtrlEntries[i]->setIndex(nr);
    }
  }
}



void mainMenu_begin(){
    String aniList = ledCtrl1.getNameList();
    menuMainSwitch1.setValueList(aniList);
    menuMainSwitch2.setValueList(aniList);
    menuMainSwitch3.setValueList(aniList);
    menuMainSwitch4.setValueList(aniList);

    aniList = rgbCtrl1.getNameList();
    menuMainRGB1.setValueList(aniList);
    menuMainRGB2.setValueList(aniList);

    aniList = neoStripeCtrl1.getNameList();
    menuMainNeo1.setValueList(aniList);
    menuMainNeo2.setValueList(aniList);

    aniList = neoMatrixCtrl1.getNameList();
    menuMainMatrix1.setValueList(aniList);
    menuMainMatrix2.setValueList(aniList);
}


/* 
ToDo: no longer used, but where should we place this
void renderDisplay(uint32_t now){
    #ifdef WITH_DISPLAY
    static uint32_t lastCycle=0;

    if (now-lastCycle > 25){
        pCube->Render();
        pCube->moveView();
      lastCycle = now;
    }
    #endif
}
*/
#include <configItem.hpp>

void TestDebug(){
  String configIn;
  JsonDocument config;

  configIn ="";
  configIn += " {                                                    \r\n";
  configIn += "     \"obj\"  : \"LED0\",                             \r\n";
  configIn += "     \"cmd\"  :    \"off\",                           \r\n";
  configIn += "     \"param\": [\"0x00FF00\",\"  2 \",\" 0 \",\"\"], \r\n";
  configIn += "     \"str\"  :  \"abc -# \",                         \r\n";
  configIn += " }                                         ";

  DeserializationError error = deserializeJson(config, configIn);
  if (error) {
    String msg = "deserializeJson() failed: ";
    msg += error.c_str(); 
    LOG(msg.c_str());
    String msg2 = msg;
  }
}


/*****************************************************************
 * 
 *    Setups
 * 
 ******************************************************************
 */

void setup() {
  blink.on();
  #ifdef WAIT_FOR_TERMINAL
  while (millis()  < WAIT_FOR_TERMINAL) {  }; 
  #endif

  Serial1.begin(115200);
  Serial1.println(" start DEBUG module ");
  debug.begin(&Serial1);

  LOG(F("setup 0:  start random"));
  randomSeed(analogRead(PIN_MIC_ANALOG));

  LOG(F("setup 0:  start Co Prozessor Arduino Nano - PWM"));
  pinMode(PIN_RESET_NANO,OUTPUT);
  digitalWrite(PIN_RESET_NANO,LOW);
  delay(5);
  digitalWrite(PIN_RESET_NANO,HIGH);

  LOG(F("setup 0:  start SPI & I2C"));
  SPI.begin();
  SPI1.begin();
  Wire.begin();
  Wire.setClock(I2C_DEFAULT_SPEED);

  LOG(F("setup 0: RTC"));
  bufferedClock.begin(&Wire,&I2C0_mutex);
  LOG(bufferedClock.getLoopDateTime().timestamp().c_str());

  
  LOG(F("setup 0: PWM expander"));
  i2c_master.begin(&Wire,&I2C0_mutex);

  LOG(F("setup 0: keyboard"));
  keyboard.begin(&Wire,0,&I2C0_mutex,keyboardStdMapping);

  LOG(F("setup 0: COM interface"));
  com.begin(&Serial,115200,SERIAL_8N1);

  LOG(F("setup 0: SD card on SPI 1..."));
    if (!globalSDcard0.begin(PIN_SD_CS)) {
      LOG(F("setup 0: SD card initialization failed!"));
    } else {
      LOG(F("setup 0: SD card initialization done."));
      LOG(F("setup 0: load config File"));
      globalHotkey.openFromFile("hotkey.cfg");
    }

  LOG(F("setup 0: Test functions"));
  TestDebug();

  LOG(F("setup 0: LED"));
  setupLed();

  blink.off();
  setupStartsecondCore = true;
  while(waitForsecondCore == true){
  }

  blink.setup(BLINK_SEQ_MAIN);
  LOG(F("setup 0: done"));
}

void setup1() {
  while(setupStartsecondCore == false){
  }

  LOG(F("setup 1:"));


  LOG(F("setup 1: TFT"));
  display.begin();

  LOG(F("setup 1: menu"));
  mainMenu_begin();
  menuHandler.begin(&menuMainHeader,(MenuEntry **)&menuMain,MENU_MAIN_COUNT,&display);

  LOG(F("setup 1: sync menu entries & ctrl objects"));
  mainMenu_syncFromCtrl();

  LOG(F("setup 1: draw menue"));
  menuHandler.loop(0);
  //LOG(F("setup 1: cube"));
  //pCube = new Cube(pTFT);  // cube includes SPI mutex handling itself

  LOG(F("setup 1: done"));
  waitForsecondCore = false;
}


/*****************************************************************
 * 
 *    Loops
 * 
 ******************************************************************
 */
void loop() {
  static uint8_t loop1State=1;
  uint32_t now = millis();
  static uint32_t lastUpdate;

  #ifdef PRINT_LOOP_STATS
    static LoopStats stats(10,1);
    stats.measureAndPrint(now,PRINT_LOOP_STATS,F_CONST("loop0 stats:"));
  #endif

  blink.loop(now);
  bufferedClock.loop(now);

  switch(loop1State){
      case 1:   ledCtrl1.loop(now);               break;
      case 2:   ledCtrl2.loop(now);               break;
      case 3:   ledCtrl3.loop(now);               break;
      case 4:   ledCtrl4.loop(now);               break;
      case 5:   rgbCtrl1.loop(now);               break;
      case 6:   rgbCtrl2.loop(now);               break;
      case 7:   com.loop();                       break;
      default:  loop1State = 0;                     break;
  }
  loop1State++;
  if (now-lastUpdate >= 20){
    keyboard.loop(now);
    lastUpdate = now;
    i2c_master.write_regSet(I2C_ADR_SLAVE,&I2C_slaveSoll,sizeof(I2C_slaveSoll),false);
  }
}




void loop1(){
  static uint8_t loop2State=1;
  uint32_t now = millis();
  String time(now/1000);
  EventType event;

  #ifdef PRINT_LOOP_STATS
    static LoopStats stats(20,5);
    stats.measureAndPrint(now,PRINT_LOOP_STATS,F_CONST("loop1 stats:"));
  #endif

  switch(loop2State){
      case 1:   neoMatrixCtrl1.loop(now);       break;
      case 2:   neoMatrixCtrl2.loop(now);       break;
      case 3:   neoStripeCtrl1.loop(now);       break;
      case 4:   neoStripeCtrl2.loop(now);       break;
      case 5:
          // update menu entries
          menuTestTime.setNewValueText(time.c_str());
          event = keyboard.getNextEvent();
          if (event != EVENT_NONE){
            while(event != EVENT_NONE){
              if (event >= EVENT_A1){
                globalHotkey.onEvent(event);
                mainMenu_syncFromCtrl();
              } else {
                menuHandler.onEvent(event);
                mainMenu_syncToCtrl();
              }
              event = keyboard.getNextEvent();
            }
          }
          break;
      case 6:  
          // draw menu            
          menuHandler.loop(now);          
          break;
      default:  loop2State = 0;                     break;
  }
  loop2State++;
}

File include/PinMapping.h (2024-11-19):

#pragma once


/*

communication channels  and adress map:

main communication chain:
USER PC  <==> (USB-serial) Raspberry Pico  (I2C0-Master) <==> (I2C-slave)  Arduino Nan



Raspberry Pico:
(I2C0-Master) <==> (I2C-slave)

SPI0    <==>    CS0: SD card
SPI1    <==>    CS1: TFT (/ Touch + GPIO pin used)
                CS2: SPI-slave-device (free)
I2C0   Pico master <==>    Slaves  (7Bit adr + R/W Bit):
                0x20: MPC23017 
                0x3X: Display  OLED or LCD 
                0x50: AT24C32
                0x58: arduino Nano - PWM LED expander
                0x68: RTC DS1307
GPIO    ==>     2 x neoLed Stripe
                2 x neoLed Matrix
GPIO    <==>    I2s  Micro
Analog  <==     Micro


Arduino Nano  (IO) ==>  4 x LED Switch  (12V)  
                   ==>  2 x RGB LED (12V)


Pin mapping Pico:
=================

----+---------------+-------------------------------------------+----------------------
PIN | Arduino       |   Raspberry PI PICO                       | Application 
    | DXX : default | GPXX : SPI        : I2C       : UART      | pin assignment
----+---------------+-------------------------------------------+----------------------
1   | D0  : SER1_TX | GP0  : SPI0_RX    : I2C0_SDA  : UART0_TX  | DEBUG_SER_TX
2   | D1  : SER1_RX | GP1  : SPI0_CSn   : I2C0_SCL  : UART0_RX  | DEBUG_SER_RX
3   |---------------|------ GND --------------------------------|------ GND -----------
4   | D2  :         | GP2  : SPI0_SCK   : I2C1_SDA  : UART0_CTS | LED_D01
5   | D3  :         | GP3  : SPI0_TX    : I2C1_SCL  : UART0_RTS | LED_DO0
6   | D4  :WIRE0_SDA| GP4  : SPI0_RX    : I2C0_SDA  : UART1_TX  | I2C_SDA
7   | D5  :WIRE0_SCL| GP5  : SPI0_CSn   : I2C0_SCL  : UART1_RX  | I2C_SCL
8   |---------------|------ GND --------------------------------|------ GND -----------
9   | D6  :         | GP6  : SPI0_SCK   : I2C1_SDA  : UART1_CTS | /RESET_NANO
10  | D7  :         | GP7  : SPI0_TX    : I2C1_SCL  : UART1_RTS | /RESET_TFT
11  | D8  : SER2_TX | GP8  : SPI1_RX    : I2C0_SDA  : UART1_TX  | TFT_LED
12  | D9  : SER2_RX | GP9  : SPI1_CSn   : I2C0_SCL  : UART1_RX  | TFT_DC
13  |---------------|------ GND --------------------------------|------ GND -----------
14  | D10 :         | GP10 : SPI1_SCK   : I2C1_SDA  : UART1_CTS | SPI_CS_TOUCH
15  | D11 :         | GP11 : SPI1_TX    : I2C1_SCL  : UART1_RTS | TOUCH_IRQ
16  | D12 :SPI1_MISO| GP12 : SPI1_RX    : I2C0_SDA  : UART0_TX  | SPI_MISO
17  | D13 :SPI1_CS  | GP13 : SPI1_CSn   : I2C0_SCL  : UART0_RX  | SPI_CS_TFT
18  |---------------|------ GND --------------------------------|------ GND -----------
19  | D14 :SPI1_SCK | GP14 : SPI1_SCK   : I2C1_SDA  : UART0_CTS | SPI_SCLK
20  | D15 :SPI1_MOSI| GP15 : SPI1_TX    : I2C1_SCL  : UART0_RTS | SPI_MOSI
----+---------------+-------------------------------------------+----------------------
----+---------------+-------------------------------------------+----------------------
21  | D16 :SPI0_MISO| GP16 : SPI0_RX    : I2C0_SDA  : UART0_TX  | SD_MISO
22  | D17 :SPI0_CS0 | GP17 : SPI0_CSn   : I2C0_SCL  : UART0_RX  | SD_CS
23  |---------------|------ GND --------------------------------|------ GND -----------
24  | D18 :SPI0_SCK | GP18 : SPI0_SCK   : I2C1_SDA  : UART0_CTS | SD_SCLK
25  | D19 :SPI0_MOSI| GP19 : SPI0_TX    : I2C1_SCL  : UART0_RTS | SD_MOSI
26  | D20 :         | GP20 : SPI0_RX    : I2C0_SDA  :           | LED_DO2
27  | D21 :         | GP21 : SPI0_CSn   : I2C0_SCL  :           | LED_DO3
28  |---------------|------ GND --------------------------------|------ GND -----------
29  | D22 :         | GP22 : SPI0_SCK   :           : UART1_CTS | I2S_SD
30  |---------------|------ RUN --------------------------------|------ RUN -----------
31  | A0  :WIRE1_SDA| GP26 : SPI1_SCK   : I2C0_SDA  : UART1_CTS | A0
32  | A1  :WIRE1_SCL| GP27 : SPI1_TX    : I2C0_SCL  : UART1_RTS | I2S_SCK
33  |---------------|------ AGND -------------------------------|------ AGND ----------
34  | A2  :         | GP28 : SPI1_SCK   : I2C0_SDA  : UART1_CTS | I2S_WS
35  |---------------|------ AREF -------------------------------|------ AREF ----------
36  |---------------|------ 3V3_OUT ----------------------------|------ 3V3_OUT -------
37  |---------------|------ 3V3_EN -----------------------------|------ 3V3_EN --------
38  |---------------|------ GND --------------------------------|------ GND -----------
39  |---------------|------ V_SYS ------------------------------|------ V_SYS ---------
40  |---------------|------ V_BUS ------------------------------|------ V_BUS ---------
----+---------------+-------------------------------------------+----------------------



Pin mapping Nano:
=================

I2C simple protocoll

ADR:        0x58    master-read     master-write
register:   0..11   N/A             PWM value 0..255

SOF | 7Bit Adr + R/W | Register Adr 8 bit | Register Value 8 Bit | EOF
SOF | AAAA AAA   R/W |  0..11             | 0..255               | EOF
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

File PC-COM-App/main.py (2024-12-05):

# -*- coding: utf-8 -*-
"""
Created on Fri Nov 29 21:56:58 2024

@author: MonekyCodeMen


To DO 

wenn files schon exestieren auf SD wird das neu übertragene file hinten angehängt !!!
vorher löschen

lösch Befehl allgemein einbauen

Scrollleisten an tree views??


"""

import os
current_directory = os.getcwd()
print("Aktuelles Arbeitsverzeichnis:", current_directory)
if (not current_directory.endswith('PC-COM-App')):
    os.chdir('PC-COM-App')
    current_directory = os.getcwd()
    print("Aktuelles Arbeitsverzeichnis:", current_directory)

import os
import tkinter as tk
from tkinter import ttk
from serial_comm import SerialCommunicator
from mode_handlers import ModeHandler
from DateCmd import DateCmd
import time
import serial
import serial.tools.list_ports
from file_manager import FileManager
from LED_config import LedConfig



class SerialCommandApp:
    def __init__(self, master):
        self.master = master
        self.master.title("Serial Command Interface")
        self.master.geometry("1400x800")

        self.mode_handler = ModeHandler(self)
        self.serial_comm  = SerialCommunicator(self)     # module to handle serial communication
        self.date_time    = DateCmd(self)                # Date cmd to read current datetime from pico
        self.file_manager = FileManager(self) 
        self.led_config   = LedConfig(self)

        # main window .. the root of all
        self.main_frame = tk.Frame(self.master)
        self.main_frame.pack(fill=tk.BOTH, expand=True, padx=5, pady=5)

        # tkframe für Port und Baudrate
        self.connection_frame =  tk.LabelFrame(self.main_frame, text="Connection")
        self.connection_frame.pack(side=tk.TOP, fill=tk.X, pady=5)
        self._setup_connection_area(self.connection_frame)

        # area with work frame and buttons
        self.mid_frame = tk.Frame(self.main_frame)
        self.mid_frame.pack(side=tk.TOP, fill=tk.BOTH, expand=True, padx=5, pady=5)
        self._fill_mid_frame(self.mid_frame)

        # tkframe für frame log
        self.message_frame = tk.LabelFrame(self.main_frame, text="Frames Log")
        self.message_frame.pack(side=tk.BOTTOM, fill=tk.BOTH, expand=True, pady=5)  # Füllt den unteren Bereich aus
        self._setup_message_area(self.message_frame)

        master.protocol("WM_DELETE_WINDOW",self._on_close)


    def __del__(self):
        self.serial_comm.disconnect()

    def _on_close(self):
        self.led_config.stop()
        self.file_manager.stop()    
        self.master.quit()
        self.master.destroy()

    def _clear_frame(self,frame):
        """Clears the content of the frame before adding new content."""
        self.led_config.stop()
        self.file_manager.stop()
        for widget in frame.winfo_children():
            widget.destroy()

    def _start_file_manager(self):
        self._clear_frame(self.work_frame)
        self.file_manager.open_file_manager(self.work_frame)

    def _start_led_config(self):
        self._clear_frame(self.work_frame)
        self.led_config.open_led_config(self.work_frame)

    def _fill_mid_frame(self, frame):
        # work_frame
        self.work_frame = tk.LabelFrame(frame, text="No function selected")
        self.work_frame.pack(side=tk.LEFT, fill=tk.BOTH, expand=True, padx=5, pady=5)

        # tkframe for button
        self.button_frame = tk.LabelFrame(frame, text="Commands")
        self.button_frame.pack(side=tk.RIGHT, fill=tk.Y, padx=10, pady=5)
        tk.Button(self.button_frame, text="Read DateTime",      command=self.date_time.read_date_time       ).pack(side=tk.TOP, pady=5)
        tk.Button(self.button_frame, text="Update DateTime",    command=self.date_time.update_date_time     ).pack(side=tk.TOP, pady=5)
        tk.Button(self.button_frame, text="File Manager",       command=self._start_file_manager            ).pack(side=tk.TOP, pady=5)
        tk.Button(self.button_frame, text="LED config",         command=self._start_led_config              ).pack(side=tk.TOP, pady=5)

    def _setup_connection_area(self, frame):
        # Selection of port
        tk.Label(frame, text="Port:").pack(side=tk.LEFT, padx=5)
        self.port_var = tk.StringVar()
        ports = [port.device for port in serial.tools.list_ports.comports()]
        self.port_menu = ttk.Combobox(frame, textvariable=self.port_var, values=ports, state="readonly")
        self.port_menu.pack(side=tk.LEFT)

        # Selection of baudrate
        tk.Label(frame, text="Baudrate:").pack(side=tk.LEFT, padx=5)
        self.baud_var = tk.StringVar(value="115200")
        self.baud_menu = ttk.Combobox(frame, textvariable=self.baud_var, values=["9600", "115200", "19200", "38400", "57600"], state="readonly")
        self.baud_menu.pack(side=tk.LEFT)

        # Connect/Disconnect Button
        self.connect_button = tk.Button(frame, text="Connect", command=self.toggle_connection)
        self.connect_button.pack(side=tk.LEFT, padx=5, pady=5)

        # Status of connection
        self.connection_status_label = tk.Label(frame, text="Disconnected", width=20)
        self.connection_status_label.pack(side=tk.LEFT, padx=5)

    def _setup_message_area(self, frame):
        # Messages Log
        #self.frame_log = tk.Text(frame, wrap=tk.WORD, state=tk.DISABLED, bg="lightgrey", height=15)  # Mehr Zeilen
        self.frame_log = tk.Text(frame, state=tk.DISABLED, bg="lightgrey", height=15)  # Mehr Zeilen
        self.frame_log.pack(side=tk.TOP, fill=tk.BOTH, expand=True, padx=5, pady=5)  # Füllt den Bereich besser aus
        scroll = tk.Scrollbar(self.frame_log, command=self.frame_log.yview)
        scroll.pack(side=tk.RIGHT, fill=tk.Y)
        self.frame_log.configure(yscrollcommand=scroll.set)
        tk.Button(frame, text="Clear Log", command=self._clear_log).pack(side=tk.LEFT, pady=2, padx=10)
        tk.Button(frame, text="save Log", command=self._save_log_to_file).pack(side=tk.LEFT, pady=2, padx = 10)
        self.log_buffer=""

    def toggle_connection(self):
        """Connect or disconnect based on the current state."""
        if self.serial_comm.is_connected():
            self.serial_comm.disconnect()
            self.connection_status_label.config(text="Disconnected")
            self.connect_button.config(text="Connect")
        else:
            self.serial_comm.connect(self.port_var.get(), int(self.baud_var.get()))
            self.connection_status_label.config(text="Connected")
            self.connect_button.config(text="Disconnect")

    def _log_recv(self, data):
        self._check_log_buffer()
        timestamp = time.strftime("%H:%M:%S", time.localtime())
        self.frame_log.config(state='normal')
        self.frame_log.insert(tk.END, f"[RECV] {timestamp}: {data}\n")
        self.frame_log.see(tk.END)
        self.frame_log.config(state='disabled')
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

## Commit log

2023-10-04 Cmd frames without parameters (use default from reset)
2023-10-05 PCB: discharge resistors
    [Pico.Light-controller.kicad_pcb]
2023-10-16 ctrl interface with time and LED for unit test
2023-10-16 rgb Led accuracy 255
2023-10-17 clamp and dim color test
2023-10-17 to do tests: colorwheel CTRl, LED test , ANI ...
2023-10-17 start test für LED CTRL objects
2023-10-18 test functions for led ani .. including led sim class
2023-10-18 CTRL constructr does not work .. removed some string objects
    [LedCtrlTest.cpp, MainTest.cpp, main.cpp]
2023-10-19 led switch blinking
2023-10-20 Led Ctrl Test blink
2023-10-21 led rgb and neostrip blinking
2023-10-26 pcb change .. LoopStats class
    [Pico.Light-controller.kicad_pcb, Pico.Light-controller.kicad_sch]
2023-10-28 std arduino spi + sd card working
    [Pico.Light-controller.kicad_pcb, Pico.Light-controller.kicad_sch]
2023-11-21 Frame structure optimized
2023-11-23 ANni Setup with str; pBuffer take over without copy (set to NULL); generate answer frame
2023-11-24 mutex spi & pcb reset button
    [Pico.Light-controller.kicad_pcb, Pico.Light-controller.kicad_sch]
2023-11-24 limit default max brightness off matrix to avoid yellow white
    [main.cpp]
2023-11-27 Matrix gif load frame by frame
2023-12-06 tft and sd not on same SPI!
    [Pico.Light-Display.kicad_sch, Pico.Light-controller.kicad_pcb, Pico.Light-controller.kicad_sch]
2023-12-06 pin assignment
2023-12-30 4 LED Switch and 2 RGB stripes
    [Gehäuse_1.FCStd, Pico.Light-Display.kicad_sch, Pico.Light-NeoPixel.kicad_sch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]
2024-01-04 issues with global objects
    [main.cpp]
2024-01-24 new pin mapping
2024-01-26 remove F_CHAR (does not work on some platforms) + Keyboard
    [main.cpp]
2024-02-18 Menu Cmd integrated Common Cmd and Pin mapping fixed to new pcb
    [main.cpp]
2024-04-21 tests fixed .. not running config test
    [LedCtrlTest.cpp, MainTest.cpp, test_SdFile.cpp]
2024-04-21 env pico std added
2024-04-29 add hotkey to main loop
    [hotkey.cfg]
2024-04-29 hotkey fix
    [hotkey.cfg]
2024-05-03 hotkey changes
    [hotkey.cfg]
2024-05-05 config changed
    [hotkey.cfg]
2024-05-15 test_colorCtrl init und triggerList
2024-05-19 color ani test finsihed .. clamp and wrapAround interface flatten
2024-06-02 ani multiflash and LED objects to new AniClass
2024-06-17 NeoMatrixGif with new AniConf und file list
    [hotkey.cfg]
2024-06-18 gif animantion loop ok .. to do: all gifs black background
    [hotkey.cfg]
2024-06-21 bug fix .. timing gif + new gif files
    [hotkey.cfg]
2024-07-22 changed gifs & config
    [hotkey.cfg]
2024-11-18 sd card files / structure added
    [hotkey - Kopie.cfg]
2024-11-19 compiler switch for display
2024-11-20 fix WS2812FX: define / undef main to enable include WS2812FX.h
    [PinMapping.h]
2024-11-20 all tests at least run: time & config still fails
    [MainTest.cpp]
2024-11-22 HW 5V SPI fixes and celandar bugfix datecheck & performance optimization
    [Pico.Light-Display.kicad_sch, Pico.Light-controller.kicad_pcb]
2024-11-23 readme & License
    [Gehäuse_1.FCStd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]
2024-11-25 parameter sep changed to ~&~ .. pc app .. error at invalid padding base 64 file read
    [hotkey - Kopie.cfg, hotkey.cfg]
2024-12-01 file copy to pico fix (delte existing files before append) mkdir rmdir delete file
    [HOTKEY2.CFG]
2024-12-05 TimeSpanExt, Time and TimerManager ready for test
2024-12-07 restructure libs fixes: split & string, time / timeSpan max & wrap around , tests
    [MainTest.cpp, main.cpp]
2025-03-18 test und todo update
